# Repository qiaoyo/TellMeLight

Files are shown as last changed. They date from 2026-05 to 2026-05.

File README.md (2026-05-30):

# TellMeLight

TellMeLight is a USB-connected AI hardware design for visualizing local AI sessions as a persistent six-slot light queue.

Current milestone: local software simulation plus a Rev A KiCad hardware baseline. No physical PCB or USB device is required yet.

## Local Commands

Run all tests on Windows:

```powershell
powershell -ExecutionPolicy Bypass -File tools/run-node.ps1 --test host/test/*.test.js
```

Start the local Host Bridge:

```powershell
powershell -ExecutionPolicy Bypass -File tools/run-node.ps1 host/src/server-cli.js
```

Send a repeatable demo event sequence while the Host Bridge is running:

```powershell
powershell -ExecutionPolicy Bypass -File tools/run-node.ps1 host/src/demo-client.js
```

Send individual adapter-style events:

```powershell
powershell -ExecutionPolicy Bypass -File tools/run-node.ps1 host/src/event-cli.js started --id codex-1 --source codex --title "Implement firmware"
powershell -ExecutionPolicy Bypass -File tools/run-node.ps1 host/src/event-cli.js approval --id codex-1 --source codex
powershell -ExecutionPolicy Bypass -File tools/run-node.ps1 host/src/event-cli.js done --id codex-1 --source codex
```

Wrap a local command as a TellMeLight session:

```powershell
$node = powershell -ExecutionPolicy Bypass -File tools/run-node.ps1 -Eval "console.log(process.execPath)"
& $node host/src/process-cli.js --source codex --id codex-1 --title "Codex run" -- codex --help
& $node host/src/process-cli.js --source smoke --id process-smoke -- powershell -NoProfile -Command "exit 0"
```

Run a real Windows Codex request as a TellMeLight session:

```powershell
$env:TELLMELIGHT_CODEX_PROXY = "http://127.0.0.1:7892"
$node = powershell -ExecutionPolicy Bypass -File tools/run-node.ps1 -Eval "console.log(process.execPath)"
& $node host/src/codex-cli.js exec -C . --sandbox read-only "Reply with exactly: TellMeLight codex smoke ok"
& $node host/src/codex-cli.js resume --last "Continue the previous TellMeLight test"
```

The package script for the same adapter is `tml-codex`.

Open the static simulator:

```text
simulator/index.html
```

Generate the Rev A KiCad hardware baseline:

```powershell
node tools/hardware/generate-rev-a-kicad.mjs
```

Generate the Rev A1 JLC-oriented hardware baseline:

```powershell
powershell -ExecutionPolicy Bypass -File tools/run-node.ps1 tools/hardware/generate-rev-a1-kicad.mjs
```

Run KiCad CLI checks with the installed Windows KiCad 10.0 path:

```powershell
& E:\kicad\bin\kicad-cli.exe sch erc --format json -o hardware/outputs/rev_a/erc.json hardware/kicad/tellmelight_rev_a/tellmelight_rev_a.kicad_sch
& E:\kicad\bin\kicad-cli.exe pcb drc --format json -o hardware/outputs/rev_a/drc.json hardware/kicad/tellmelight_rev_a/tellmelight_rev_a.kicad_pcb
& E:\kicad\bin\kicad-cli.exe sch erc --format json -o hardware/outputs/rev_a1/erc.json hardware/kicad/tellmelight_rev_a1/tellmelight_rev_a1.kicad_sch
& E:\kicad\bin\kicad-cli.exe pcb drc --format json -o hardware/outputs/rev_a1/drc.json hardware/kicad/tellmelight_rev_a1/tellmelight_rev_a1.kicad_pcb
```

## Simulator Interaction

- Click any of the six light slots to select it.
- Use `Set Running`, `Set Approval`, `Set Done`, or `Set Error` to update the selected session.
- Use `Clear Selected` to remove the selected visible session and compact later sessions left.
- `Add Running` appends a new running session on the newest/rightmost side.

## Milestone 1 Contents

- FIFO session model.
- Local API event schema.
- HID display frame encoder.
- Browser simulator.
- Hardware architecture notes.
- Generic process wrapper adapter.
- Direct Windows Codex JSON session adapter.
- Rev A KiCad hardware baseline with BOM, PCB floorplan, and power-budget simulation.
- Rev A1 JLC-oriented KiCad baseline with 4-layer PCB, JLC sourcing table, pogo/debug pads, and manufacturing readiness notes.

## Out Of Scope For Milestone 1

- Real USB HID writer.
- Firmware build.
- Fabrication-ready schematic signoff, final routing, enclosure CAD, and optical validation.
- Tool-specific log parsers for Codex, Claude, Cursor, or other AI tools.

## Design Docs

- `docs/superpowers/specs/2026-05-29-tellmelight-design.md`
- `docs/superpowers/specs/2026-05-30-rev-a-kicad-hardware-design.md`
- `docs/superpowers/specs/2026-05-30-rev-a1-jlc-fabrication-candidate-design.md`
- `docs/superpowers/specs/2026-05-29-adapter-foundation-design.md`
- `docs/adapters/contract.md`
- `docs/superpowers/brainstorm/2026-05-29-tellmelight-progress.md`
- `docs/superpowers/plans/2026-05-29-local-simulation-foundation.md`
- `docs/superpowers/plans/2026-05-30-rev-a-kicad-hardware.md`
- `docs/superpowers/plans/2026-05-30-rev-a1-jlc-fabrication-candidate.md`

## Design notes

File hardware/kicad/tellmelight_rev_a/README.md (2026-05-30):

# TellMeLight Rev A KiCad Project

Generated: 2026-05-30

## Contents

- `tellmelight_rev_a.kicad_pro`: KiCad project.
- `tellmelight_rev_a.kicad_sch`: block-level schematic/net plan for Rev A.
- `tellmelight_rev_a.kicad_sym` and `sym-lib-table`: local placeholder symbols so KiCad can export a review BOM.
- `tellmelight_rev_a.kicad_pcb`: PCB placement baseline with real KiCad stock footprints.

## Important Boundary

This is a Rev A CAD baseline for review. It is not a fabrication release until the pin-by-pin schematic, routing, footprint models, and DFM are reviewed.

## Visual Mapping

- D1 and D2: left long bar, oldest side.
- D3: left middle short bar.
- D4: right middle short bar.
- D5 and D6: right long bar, newest side.

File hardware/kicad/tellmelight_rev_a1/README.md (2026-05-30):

# TellMeLight Rev A1 KiCad Project

Generated: 2026-05-30

## Contents

- `tellmelight_rev_a1.kicad_pro`: KiCad project.
- `tellmelight_rev_a1.kicad_sch`: block-level schematic/net plan for Rev A1.
- `tellmelight_rev_a1.kicad_sym` and `sym-lib-table`: local symbols so KiCad can export a review BOM.
- `tellmelight_rev_a1.kicad_pcb`: 4-layer PCB floorplan with stock KiCad footprints.

## Important Boundary

This is a Rev A1 JLC-oriented CAD baseline for review. It is not a fabrication release until the pin-by-pin schematic, routing, footprint models, JLC BOM matching, and DFM are reviewed.

## Manufacturing Direction

- 4-layer PCB.
- Double-sided SMT assembly.
- No assumed user hand-soldering.
- Pogo/test pads replace the visible SWD header direction.
- Front side is kept mostly optical; back side carries logic, USB, power, and service controls.

## Visual Mapping

- D1 and D2: left long bar, oldest side.
- D3: left middle short bar.
- D4: right middle short bar.
- D5 and D6: right long bar, newest side.

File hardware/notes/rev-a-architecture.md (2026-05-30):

# TellMeLight Rev A Hardware Architecture Notes

Rev A is now a KiCad hardware baseline for an integrated USB device. It is meant for design review and iteration, not direct fabrication signoff.

## Selected Direction

- USB-C for power and data.
- RP2040-class USB MCU.
- LP5024-class I2C RGB LED driver.
- six RGB light zones using 18 LED driver channels.
- Four visible diffuser bars:
  - Left long bar has two zones.
  - Left middle bar has one zone.
  - Right middle bar has one zone.
  - Right long bar has two zones.

## KiCad Baseline Boundary

This milestone creates:

- KiCad project files.
- Block-level schematic/net-plan notes.
- PCB floorplan and component placement using real KiCad stock footprints.
- Rev A BOM.
- Power-budget simulation notes.
- KiCad CLI ERC, DRC, and export artifacts when the local KiCad installation supports them.

This milestone does not complete pin-by-pin schematic signoff, final routing, enclosure CAD, diffuser optical validation, or release-to-fabrication DFM.

## Open Hardware Questions

- Whether each light zone can use one RGB LED or needs multiple LEDs for smoother diffusion.
- Exact USB-C protection and ESD component choices.
- Exact LP5024 sourcing option; the baseline uses the 32-pin 4 x 4 mm VQFN/WQFN footprint class.
- Mechanical light-isolation wall thickness between split long-bar zones.

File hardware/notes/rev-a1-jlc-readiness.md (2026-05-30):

# Rev A1 JLC Readiness Notes

Date: 2026-05-30

Rev A1 is a local fabrication-candidate baseline, not an order release.

## Confirmed Direction

- No assumed user hand-soldering.
- JLC DFM review before ordering.
- double-sided SMT assembly pricing and capability check.
- LP5024 VQFN exposed-pad paste and thermal-pad review.
- RGB LED pinout verification against the final JLC selected part.
- USB-C connector footprint and shell grounding review.

## Current JLC Candidate Parts

| Designator | Part | JLC candidate |
| --- | --- | --- |
| U1 | RP2040 | C2040 |
| U2 | LP5024RSMR | C427525 |
| U3 | W25Q32JVSSIQ | C82344 |
| U4 | AP2112K-3.3TRG1 | C51118 |
| U5 | TPD2EUSB30DRTR | C94934 |
| J1 | TYPE-C-31-M-12 | C165948 |
| D1-D6 | S4-3528RGBTA-A | C2827321 |

## Remaining Order Blockers

- Replace block-level schematic review symbols with a pin-by-pin schematic before fabrication.
- Verify the 4-pin RGB LED pad mapping against the final part datasheet.
- Review USB D+/D- routing, ESD placement, and differential pair geometry.
- Review 4-layer stackup, impedance assumptions, and copper pours against the selected JLC service.
- Export JLC BOM and CPL files in the exact order-site format after final component matching.
- Decide whether the first paid order uses black solder mask plus ENIG or a lower-cost engineering finish.

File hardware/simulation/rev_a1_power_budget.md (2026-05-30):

# Rev A1 Power Budget Simulation

Date: 2026-05-30

This is a local engineering current budget for the KiCad Rev A1 JLC-oriented baseline. It is not a SPICE model.

USB current target: keep normal operation comfortably below 500 mA.

| Scenario | 3V3 load | LED channels on | LED current/channel | LED rail current | Approx USB current | LDO dissipation |
| --- | ---: | ---: | ---: | ---: | ---: | ---: |
| Idle off | 38 mA | 0 | 0 mA | 0 mA | 38 mA | 65 mW |
| Typical visible load | 45 mA | 18 | 5 mA | 90 mA | 135 mA | 77 mW |
| Breathing peak | 50 mA | 18 | 10 mA | 180 mA | 230 mA | 85 mW |
| Worst-case all channels | 70 mA | 18 | 20 mA | 360 mA | 430 mA | 119 mW |

## Interpretation

- Typical visible load keeps the device comfortably inside the USB current target.
- Worst-case all channels still fits the target budget on paper, but firmware should cap default brightness well below that state.
- The AP2112K-class LDO only supplies 3V3 logic current; LED current is budgeted on the USB VBUS LED rail.
- The S4-3528RGBTA-A RGB LED candidate remains a sample-and-review item because optical output and diffuser losses will drive the final current limit.

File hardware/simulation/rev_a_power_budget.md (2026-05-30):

# Rev A Power Budget Simulation

Date: 2026-05-30

This is a local engineering current budget for the KiCad Rev A baseline. It is not a SPICE model.

| Scenario | 3V3 load | LED channels on | LED current/channel | LED rail current | Approx USB current | LDO dissipation |
| --- | ---: | ---: | ---: | ---: | ---: | ---: |
| Idle off | 38 mA | 0 | 0 mA | 0 mA | 38 mA | 65 mW |
| Typical visible load | 45 mA | 18 | 5 mA | 90 mA | 135 mA | 77 mW |
| Breathing peak | 50 mA | 18 | 10 mA | 180 mA | 230 mA | 85 mW |
| Worst-case all channels | 70 mA | 18 | 20 mA | 360 mA | 430 mA | 119 mW |

## Interpretation

- Typical visible load keeps the device comfortably inside a 500 mA USB current budget.
- Worst-case all channels still fits the target budget on paper, but firmware should cap default brightness well below that state.
- The AP2112K-class LDO only supplies 3V3 logic current; LED current is budgeted on the USB VBUS LED rail.
- The RGB LED part remains a sample-and-review item because optical output and diffuser losses will drive the final current limit.

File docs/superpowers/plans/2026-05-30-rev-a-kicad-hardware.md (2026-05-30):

# Rev A KiCad Hardware Implementation Plan

> **For agentic workers:** REQUIRED SUB-SKILL: Use superpowers:subagent-driven-development (recommended) or superpowers:executing-plans to implement this plan task-by-task. Steps use checkbox (`- [ ]`) syntax for tracking.

**Goal:** Add a verified Rev A KiCad hardware baseline for the integrated TellMeLight USB light device.

**Architecture:** A small Node generator writes deterministic hardware documentation, BOM tables, and KiCad project scaffolding. A KiCad Python generator uses the installed KiCad 10.0 `pcbnew` API to create the PCB with real library footprints and the approved six-zone/four-bar placement. KiCad CLI then runs ERC/DRC and exports review/manufacturing artifacts.

**Tech Stack:** KiCad 10.0.3 CLI, KiCad `pcbnew` Python API, JavaScript ES modules, Node `node:test`, PowerShell runner.

---

## File Structure

- Create `hardware/kicad/tellmelight_rev_a/`: KiCad project, schematic, board, local symbol metadata, and generated design README.
- Create `hardware/bom/rev_a_bom.csv`: human-readable baseline BOM.
- Create `hardware/simulation/rev_a_power_budget.csv`: machine-readable current budget.
- Create `hardware/simulation/rev_a_power_budget.md`: readable power simulation notes.
- Create `hardware/outputs/rev_a/`: ERC, DRC, and exported KiCad output files.
- Create `tools/hardware/generate-rev-a-kicad.mjs`: deterministic project/document generator.
- Create `tools/hardware/generate_rev_a_board.py`: KiCad `pcbnew` board generator.
- Create `host/test/hardware-assets.test.js`: repository tests for hardware outputs and decisions.
- Modify `hardware/notes/rev-a-architecture.md`: move from "no PCB" note to Rev A baseline note.
- Modify `docs/superpowers/brainstorm/2026-05-29-tellmelight-progress.md`: record this checkpoint.
- Modify `README.md`: add the hardware workspace and KiCad commands.

## Task 1: Spec And Plan

- [ ] Save the approved Rev A design spec at `docs/superpowers/specs/2026-05-30-rev-a-kicad-hardware-design.md`.
- [ ] Save this implementation plan at `docs/superpowers/plans/2026-05-30-rev-a-kicad-hardware.md`.
- [ ] Run `git diff --check`.
- [ ] Commit as `docs: plan rev a kicad hardware`.

## Task 2: Hardware Artifact Tests

- [ ] Add `host/test/hardware-assets.test.js`.
- [ ] Tests must assert the Rev A spec mentions `RP2040`, `LP5024`, `USB-C`, `six logical session slots`, and `VQFN-32`.
- [ ] Tests must assert the generated BOM contains `RP2040`, `LP5024`, `W25Q32`, `AP2112K`, `TPD2EUSB30`, `USB_C`, and `RGB_LED`.
- [ ] Tests must assert the generated PCB contains the required references `U1`, `U2`, `J1`, `D1` through `D6`, `SWD1`, `SW1`, and `SW2`.
- [ ] Run `powershell -ExecutionPolicy Bypass -File tools/run-node.ps1 --test host/test/hardware-assets.test.js` and confirm the new tests fail before generation.

## Task 3: Generators And Documentation

- [ ] Add `tools/hardware/generate-rev-a-kicad.mjs` with deterministic output paths.
- [ ] Add `tools/hardware/generate_rev_a_board.py` that loads KiCad stock footprints and places the core Rev A components.
- [ ] Update `hardware/notes/rev-a-architecture.md` with the actual KiCad baseline scope.
- [ ] Update `README.md` with hardware commands and artifact paths.
- [ ] Update the Superpowers progress log with the Rev A hardware checkpoint.

## Task 4: Generate Rev A Assets

- [ ] Run `node tools/hardware/generate-rev-a-kicad.mjs`.
- [ ] Confirm these files are created:
  - `hardware/kicad/tellmelight_rev_a/tellmelight_rev_a.kicad_pro`
  - `hardware/kicad/tellmelight_rev_a/tellmelight_rev_a.kicad_sch`
  - `hardware/kicad/tellmelight_rev_a/tellmelight_rev_a.kicad_pcb`
  - `hardware/bom/rev_a_bom.csv`
  - `hardware/simulation/rev_a_power_budget.csv`
  - `hardware/simulation/rev_a_power_budget.md`
- [ ] Run `powershell -ExecutionPolicy Bypass -File tools/run-node.ps1 --test host/test/hardware-assets.test.js` and confirm the hardware tests pass.

## Task 5: KiCad CLI Verification And Exports

- [ ] Run `E:\kicad\bin\kicad-cli.exe sch erc --format json -o hardware/outputs/rev_a/erc.json hardware/kicad/tellmelight_rev_a/tellmelight_rev_a.kicad_sch`.
- [ ] Run `E:\kicad\bin\kicad-cli.exe sch export bom -o hardware/outputs/rev_a/bom_from_kicad.csv hardware/kicad/tellmelight_rev_a/tellmelight_rev_a.kicad_sch`.
- [ ] Run `E:\kicad\bin\kicad-cli.exe sch export netlist -o hardware/outputs/rev_a/netlist.xml hardware/kicad/tellmelight_rev_a/tellmelight_rev_a.kicad_sch`.
- [ ] Run `E:\kicad\bin\kicad-cli.exe pcb drc --format json -o hardware/outputs/rev_a/drc.json hardware/kicad/tellmelight_rev_a/tellmelight_rev_a.kicad_pcb`.
- [ ] Run `E:\kicad\bin\kicad-cli.exe pcb export gerbers -o hardware/outputs/rev_a/gerbers hardware/kicad/tellmelight_rev_a/tellmelight_rev_a.kicad_pcb`.
- [ ] Run `E:\kicad\bin\kicad-cli.exe pcb export drill -o hardware/outputs/rev_a/drill hardware/kicad/tellmelight_rev_a/tellmelight_rev_a.kicad_pcb`.
- [ ] Run `E:\kicad\bin\kicad-cli.exe pcb export pos -o hardware/outputs/rev_a/pos hardware/kicad/tellmelight_rev_a/tellmelight_rev_a.kicad_pcb`.
- [ ] Run `E:\kicad\bin\kicad-cli.exe pcb export step -o hardware/outputs/rev_a/tellmelight_rev_a.step hardware/kicad/tellmelight_rev_a/tellmelight_rev_a.kicad_pcb`.
- [ ] Run `E:\kicad\bin\kicad-cli.exe pcb render -o hardware/outputs/rev_a/tellmelight_rev_a_top.png --side top --width 1600 --height 1200 hardware/kicad/tellmelight_rev_a/tellmelight_rev_a.kicad_pcb`.
- [ ] Record any warnings in `hardware/outputs/rev_a/verification-summary.md`.

## Task 6: Final Repository Verification

- [ ] Run `powershell -ExecutionPolicy Bypass -File tools/run-node.ps1 --test host/test/*.test.js`.
- [ ] Run `git diff --check`.
- [ ] Review `git status --short`.
- [ ] Commit as `feat: add rev a kicad hardware baseline`.
- [ ] Push `feature/local-simulation-foundation`.

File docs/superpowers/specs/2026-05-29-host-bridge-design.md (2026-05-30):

# TellMeLight Host Bridge Design

Date: 2026-05-29

## Goal

Build a local-only Host Bridge service that turns normalized AI session events into the six-slot TellMeLight model and streams the current slots to the browser simulator.

This milestone still does not touch real PCB, firmware, or USB hardware.

## Scope

Included:

- Local HTTP service using Node built-in modules.
- `POST /v1/events` for normalized session events.
- `GET /v1/slots` for the current six-slot state.
- `GET /v1/stream` using Server-Sent Events for live simulator updates.
- A small manual event client for local demos.
- Simulator support for connecting to the Host Bridge, while keeping manual buttons as a fallback.

Excluded:

- Real USB HID device writing.
- WebSocket support.
- Real Codex, Claude, Cursor, or local-agent adapters.
- Persistence across process restarts.

## Architecture

The Host Bridge is a thin service layer around the existing tested core:

- `host/src/schema.js` validates and normalizes external event payloads.
- `host/src/fifo.js` owns session ordering and state transitions.
- A new bridge state module owns the mutable in-memory model and subscriber notification.
- A new HTTP server module maps routes to bridge operations.
- A demo client sends example events to the service.
- The simulator first tries the service stream. If unavailable, it stays usable in manual mode.

This keeps adapter work separate from the core display model. Future tool adapters can send the same event payloads to `POST /v1/events`.

## API

`GET /v1/slots`

- Returns HTTP 200 JSON.
- Body contains `revision` and `slots`.
- Each slot includes `slot`, `id`, `source`, `title`, `state`, and `updatedAt`.
- Empty slots are represented as `id: null`, `state: "idle"`.

`POST /v1/events`

- Accepts JSON with `source`, `session_id`, `event`, optional `state`, optional `title`, optional `time`, and optional `outcome`.
- Uses the existing normalizer and FIFO core.
- Returns HTTP 202 JSON containing the updated slot snapshot.
- Invalid JSON or invalid event payloads return HTTP 400 JSON with an `error` field.

`GET /v1/stream`

- Returns `text/event-stream`.
- Sends the current snapshot immediately.
- Sends another snapshot whenever `POST /v1/events` changes the model.
- Uses event name `slots`.

## Simulator Behavior

On load, the simulator opens `/v1/stream` against `http://localhost:8787`.

- If the stream connects, incoming slot snapshots drive the light display and JSON panel.
- Manual controls remain available and send events to `POST /v1/events`.
- If the service is unavailable or a POST fails, the simulator falls back to the existing in-browser manual state.
- Selected-slot UI remains local to the simulator; the Host Bridge only owns session state.

## Manual Demo

A new demo script sends a repeatable sequence:

1. Start session A.
2. Start session B.
3. Change A to approval.
4. End B as done.
5. Start enough extra sessions to demonstrate FIFO movement.

The script targets `http://localhost:8787` by default.

## Testing

Tests cover:

- Slot snapshot shape from the bridge state module.
- Event application and subscriber notification.
- HTTP `GET /v1/slots`.
- HTTP `POST /v1/events` success and invalid-payload failure.
- SSE stream sends the current snapshot and updates.
- Simulator assets contain the Host Bridge connection and fallback hooks.

Full verification remains:

```powershell
powershell -ExecutionPolicy Bypass -File tools/run-node.ps1 --test host/test/*.test.js
```

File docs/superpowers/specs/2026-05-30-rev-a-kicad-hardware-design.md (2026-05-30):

# Rev A KiCad Hardware Design

Date: 2026-05-30

## Goal

Create the first local KiCad hardware baseline for TellMeLight: a USB-C connected, integrated PCB that drives six persistent AI-session light zones through a four-bar diffuser layout.

This baseline is intended for design review, firmware bring-up planning, and PCB iteration. It is not a release-to-fabrication signoff without a human schematic, footprint, and DFM review.

## Approved Product Direction

- Wired USB-C for power and data.
- No development board in the product; the PCB is integrated.
- Six logical session slots are kept as a FIFO queue.
- Idle slots are off.
- Running and approval states can breathe in firmware.
- Done and error states remain visible until the user or host clears them.
- Visual core uses four ByteDance-style vertical diffuser bars:
  - Left long bar contains two light zones.
  - Left middle short bar contains one light zone.
  - Right middle short bar contains one light zone.
  - Right long bar contains two light zones.
- The left long bar is slightly shorter than the right long bar.
- The two middle bars are equal size; the left short bar sits lower and the right short bar sits only slightly higher.
- Bar shapes are soft, rounded, irregular trapezoids:
  - Left long, right long, and left middle bars have their shorter side facing right.
  - Right middle bar has its shorter side facing left.

## Electrical Architecture

### USB And MCU

- Use an RP2040-class USB microcontroller as the main controller.
- Use USB full-speed data on the USB-C receptacle.
- Add 27 ohm series resistors on USB D+ and D- near the MCU.
- Add USB ESD protection close to the USB-C connector.
- Add CC pull-down resistors so the board enumerates as a USB-C device.
- Use an external QSPI flash for RP2040 firmware storage.
- Add 12 MHz crystal support for the RP2040 clock.
- Expose SWD, reset, boot select, 3V3, and GND pads for bring-up.

### LED Driver

- Use an LP5024-class 24-channel I2C constant-current RGB LED driver.
- Use 18 channels for six RGB zones; leave six channels reserved.
- Power logic from 3V3 and LED anodes from the USB 5V LED rail unless review later moves LED power to 3V3.
- Use one common-anode RGB LED per zone for Rev A. The mechanical diffuser may later require multiple emitters per zone, but that belongs to Rev B after optical tests.
- I2C pull-ups live on the 3V3 rail.
- Address pins are strapped for a single driver at the base address.

### Power

- USB VBUS enters through input protection and feeds:
  - 5V LED rail.
  - 3V3 regulator for MCU, flash, and LED driver logic.
- Use an AP2112K-3.3-class LDO in SOT-23-5 for the first baseline.
- Size decoupling locally:
  - USB input bulk capacitance near the connector/regulator.
  - 3V3 regulator input/output capacitors near the LDO.
  - One local 100 nF decoupler per IC supply cluster.
  - LED rail bulk capacitance near the LED driver/LED zones.

## Mechanical And PCB Intent

- PCB outline is a compact near-square core display module with enough room for USB-C, programming pads, and diffuser alignment.
- Front-side LED placement follows the four-bar visual layout.
- Silkscreen and drawing layers mark diffuser bar boundaries, split points in long bars, and session indices.
- Rev A PCB is a placement and routing baseline:
  - The KiCad board must contain real footprints for the main components.
  - The LED geometry must match the approved visual direction.
  - The first generated PCB may use simple routing scaffolds and explicit review notes rather than final hand-tuned high-density routing.

## BOM Intent

The baseline BOM must include:

- RP2040 MCU, QFN-56 7 x 7 mm.
- LP5024 LED driver, VQFN-32 RSM 4 x 4 mm.
- USB-C USB2 receptacle.
- AP2112K-3.3-class LDO.
- TPD2EUSB30-class USB ESD protection.
- W25Q32JVSS-class QSPI flash.
- 12 MHz crystal and load capacitors.
- Six common-anode PLCC-6 RGB LEDs.
- USB resistors, CC resistors, I2C pull-ups, boot/reset passives, decoupling capacitors, and test pads.

## Simulation And Checks

Rev A local simulation means engineering calculation and CAD checks, not SPICE signoff:

- Power budget table for idle, typical, and worst-case LED current.
- KiCad schematic ERC report.
- KiCad PCB DRC report.
- KiCad exports for Gerber, drill, position, STEP, PDF/SVG or rendered preview when supported by the installed KiCad CLI.
- Repository tests that confirm required hardware artifacts and component decisions exist.

## Open Review Items

- Confirm exact RGB LED optical output, viewing angle, color balance, and availability.
- Confirm whether LED anodes stay on USB 5V or move to 3V3 after brightness tests.
- Confirm USB-C receptacle mechanical model and shell grounding strategy.
- Confirm final enclosure, diffuser material, wall thickness, and light isolation.
- Confirm manufacturability of QFN/VQFN assembly for the intended PCB vendor.

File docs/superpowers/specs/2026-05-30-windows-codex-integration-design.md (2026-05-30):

# Windows Codex Integration Design

Date: 2026-05-30

## Goal

Connect TellMeLight directly to the local Windows Codex CLI conversation/session flow.

This is not a generic process wrapper. It uses real `codex exec --json` and `codex exec resume --json` output so TellMeLight can key sessions by Codex `thread_id`.

## Verified Local Codex

- Executable: `codex.exe`
- Version: `codex-cli 0.133.0-alpha.1`
- Install path: VS Code ChatGPT extension Windows binary.
- Working network path: proxy `http://127.0.0.1:7892`.
- Verified request:
  - Command: `codex exec --json -C . --sandbox read-only "Reply with exactly: TellMeLight codex smoke ok"`
  - Observed `thread.started` with a real `thread_id`.
  - Observed final agent message `TellMeLight codex smoke ok`.

## Scope

Included:

- `tml-codex` command for new Codex turns.
- `tml-codex resume` command for continuing a recorded Codex session.
- Real Codex JSONL parsing.
- TellMeLight session ID from Codex `thread_id`.
- Running/done/error mapping from Codex turn and process lifecycle.
- Approval mapping when Codex JSONL contains approval-oriented event or item status fields.
- Proxy override through `--tml-proxy` or `TELLMELIGHT_CODEX_PROXY`.

Excluded:

- Interactive TUI scraping.
- Private Codex database parsing.
- Mutating Codex config files.
- Firmware, HID output, PCB, and schematic work.

## Command Shape

New request:

```powershell
$env:TELLMELIGHT_CODEX_PROXY = "http://127.0.0.1:7892"
$node = powershell -ExecutionPolicy Bypass -File tools/run-node.ps1 -Eval "console.log(process.execPath)"
& $node host/src/codex-cli.js exec -C . --sandbox read-only "Reply with exactly: TellMeLight codex smoke ok"
```

Resume most recent non-interactive Codex session:

```powershell
& $node host/src/codex-cli.js resume --last "Continue the previous TellMeLight test"
```

TellMeLight-only flags:

- `--tml-url`: Host Bridge base URL.
- `--tml-title`: visible title before Codex emits details.
- `--tml-proxy`: proxy URL assigned to `HTTP_PROXY`, `HTTPS_PROXY`, `http_proxy`, and `https_proxy` for the Codex child process.

## Event Mapping

- `thread.started`: send TellMeLight `started` with `state: running` and `session_id` equal to the Codex thread ID.
- `turn.started`: send `state_changed` to `running` if the thread is known.
- JSONL event or item fields containing approval/waiting-for-approval semantics: send `state_changed` to `approval`.
- `turn.completed`: send `ended` with `outcome: success`.
- Codex JSONL error events or non-zero process exit: send `ended` with `outcome: error`.

The CLI passes Codex stdout/stderr through so it remains usable as a Codex command.

## Testing

Unit tests cover command parsing, proxy environment application, JSONL event mapping, and process lifecycle behavior with fake spawn/send functions.

Real smoke test uses the local Windows Codex CLI with proxy `http://127.0.0.1:7892` and a temporary Host Bridge.

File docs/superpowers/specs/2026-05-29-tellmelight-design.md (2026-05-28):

# TellMeLight Design

Date: 2026-05-29

## Summary

TellMeLight is a USB-connected AI hardware device that visualizes local AI sessions through a persistent six-slot light queue. The physical design uses a four-bar, ByteDance-style top-face rhythm while preserving six independent RGB light zones by splitting both long bars into two zones.

The first product direction is an integrated PCB with a USB-C interface, RP2040-class MCU, LP5024-class I2C RGB LED driver, six RGB light zones, a local Host Bridge service, firmware-side light rendering, and a browser simulator for pre-hardware validation.

## Goals

- Design an integrated PCB hardware product, not a breadboard or development-board MVP.
- Connect local AI tools to a small desk light display over USB.
- Show up to six AI sessions as a FIFO queue.
- Keep completed and errored sessions visible until cleared or evicted.
- Build an automation-friendly repo structure where specs, host software, firmware, hardware, and verification can evolve together.
- Use AI-assisted design with explicit verification gates rather than blind one-click hardware generation.

## Non-Goals

- No Wi-Fi or wireless mode in the first hardware target.
- No FPGA or HDL-based implementation unless the architecture changes later.
- No PCB layout before the six-slot logic and simulator are executable and testable.
- No direct dependency on a single AI tool's log format in the core state machine.

## Visual Design

The device is a compact desk puck with a rounded rectangular body and four vertical diffuser bars on the top face.

The final silhouette:

- Left long bar is slightly shorter than the right long bar.
- The two middle bars are the same size.
- Left middle bar sits lower.
- Right middle bar sits only slightly higher than the left middle bar.
- The visual style intentionally follows a ByteDance-style four-bar rhythm.

The four visible bars represent six internal light zones:

- Left long bar: two internal zones.
- Left middle short bar: one zone.
- Right middle short bar: one zone.
- Right long bar: two internal zones.

## Session Queue

The six light zones form a FIFO queue.

- New sessions enter the rightmost slot.
- Existing sessions shift left by one slot when a new session starts.
- If a seventh new session arrives, slot 1, the top of the left long bar, is evicted.
- Evicted sessions can remain in host-side history but are no longer displayed.
- Completed and errored sessions remain visible until evicted or explicitly cleared.
- `cleared` removes a target session, compacts remaining visible sessions left, and leaves the newest-side empty slot idle.

## State Language

Each visible slot has one state:

- `running`: cyan/blue, continuous slow breathing.
- `approval`: amber, continuous attention pulse.
- `done`: green, persistent steady light.
- `error`: red, persistent steady light or slow warning pulse.
- `idle`: off.

Animation is persistent for active states; it is not a one-time notification. Done and error states must remain visible so the user can notice them later.

## Hardware Architecture

The confirmed first hardware target:

- USB-C for power and data.
- RP2040-class USB MCU.
- LP5024-class I2C RGB LED driver.
- Six RGB light zones using 18 LED driver channels.
- Integrated PCB.

The LED driver route is preferred over addressable RGB LEDs because it is more maintainable and product-like:

- MCU writes stable I2C commands instead of timing-sensitive one-wire LED data.
- LED current and color behavior are controlled by a dedicated driver.
- Firmware and hardware tests can isolate the driver, channels, and zones.
- The architecture leaves channel headroom with a 24-channel driver.

Open hardware decision:

- Decide whether each light zone uses one RGB LED or multiple LEDs under the same diffuser zone. If each zone needs multiple LEDs for smoother diffusion, the design may use more driver channels or parallel same-color LEDs with careful current design.

## Software Boundary

TellMeLight is split into host software, device firmware, and hardware output.

Host Bridge owns:

- Local AI tool integration.
- Session discovery.
- Normalized event ingestion.
- Session registry.
- FIFO queue state machine.
- Persistence and history.
- Slot output to simulator and USB device.

Device firmware owns:

- USB HID frame receive.
- Frame validation.
- State-to-light rendering.
- Breathing and pulse curves.
- Global brightness limits.
- I2C updates to the LP5024-class LED driver.

The LED driver owns:

- PWM/current output for the RGB channels.

## Local API

The Host Bridge exposes a local API for adapters and debugging:

- `POST /v1/events`: receive normalized session events.
- `GET /v1/slots`: return the current six-slot state.
- `WS /v1/stream`: stream slot updates to simulator or dashboard clients.

Minimal event payload:

```json
{
  "source": "codex",
  "session_id": "abc123",
  "event": "started",
  "state": "running",
  "title": "optional short label",
  "time": "2026-05-29T00:00:00+08:00"
}
```

Event semantics:

- `started`: if `session_id` is new, shift FIFO left and insert into slot 6 as `running`; if known, update in place.
- `state_changed`: update known sessions in place; create unknown sessions to keep adapters forgiving.
- `ended`: does not remove the session; sets state to `done` unless outcome is `error`.
- `cleared`: removes a visible session, compacts remaining sessions left, and sets the empty newest-side slot to idle.
- `evicted`: internal Host Bridge log/UI event when a seventh new session pushes slot 1 out.

## USB Device Protocol

Host-side APIs remain JSON-based. The product device protocol is USB HID.

Product path:

- USB HID output report.
- Fixed-size binary frame, initially 64 bytes.
- No user-facing serial port required.

Development path:

- Optional USB CDC serial debug console in development firmware.
- CDC is for logs and manual testing, not the primary product protocol.

Proposed 64-byte display frame:

- `magic[2]`: `TL`.
- `version`: protocol version.
- `seq`: incrementing frame number.
- `brightness`: global brightness, `0..255`.
- `flags`: global display options.
- `slots[6]`: each slot carries `state`, `anim`, `intensity`, `age`, `label_hash`, and reserved bytes.
- `crc8`: lightweight frame check.

The firmware owns the default state palette. Host-side RGB overrides can be added later as an extension, but the first protocol should send display intent rather than raw colors.

## Firmware Rendering

Host Bridge sends slot states only when FIFO or session status changes. It does not stream every animation frame.

Firmware computes animations locally:

- Keeps the last valid frame.
- Renders breathing and pulse curves on the device.
- Updates the LED driver at a steady frame rate.
- Ignores invalid frames.

Failsafe behavior:

- USB connected but no recent update: keep the last valid frame.
- Host heartbeat lost for a longer timeout: optionally dim all active slots to show stale data.
- Invalid frame: ignore it and keep the previous valid frame.

## Host Bridge Modules

Recommended internal structure:

- Inputs:
  - HTTP event API.
  - Manual test client.
  - Tool-specific adapters for Codex, Claude, Cursor, and future local agents.
- Core:
  - Event validation.
  - Session registry.
  - FIFO queue state machine.
  - Persistence and history.
- Outputs:
  - USB HID device writer.
  - Web simulator stream.
  - Debug REST API.
  - Logs.

Design rules:

- Adapters are disposable and translate tool-specific signals into normalized events.
- FIFO core is durable and tested independently.
- Outputs are replaceable, so the same six-slot model can drive a simulator before hardware exists.

## Repository Structure

Initial repo areas:

- `docs/`: design specs, progress logs, decisions, checklists.
- `host/`: Bridge service, API, FIFO core, adapters, simulator connection.
- `firmware/`: RP2040 firmware, HID receive, animation renderer, LP5024-class driver.
- `hardware/`: PCB, symbols/footprints, enclosure notes, manufacturing outputs.
- `simulator/`: browser-visible light simulator and visual validation tools.
- `tools/`: automation scripts for checks, generated outputs, and design support.

## Automation Pipeline

The automation goal is AI-assisted design with repeatable checks.

Pipeline stages:

- Spec: requirements, state semantics, six-slot mapping, selected components.
- Schematic: USB-C input, RP2040-class MCU, LP5024-class RGB LED driver, power, ESD/protection, debug/programming pads.
- PCB: board outline, LED placement, diffuser and light-isolation assumptions, routing, DRC.
- Firmware: HID receive, renderer, LP5024-class driver.
- Host: local API, FIFO model, simulator, USB HID writer.

Verification gates:

- Hardware:
  - Electrical rule check.
  - PCB design rule check.
  - BOM completeness.
  - Footprint presence.
  - USB/power review checklist.
- Software:
  - FIFO state-machine tests.
  - API schema tests.
  - HID frame encoder tests.
  - Firmware renderer tests.
  - Simulator screenshot checks.

## First Implementation Milestone

Create a repo skeleton and executable software simulation before starting PCB layout.

Milestone scope:

- Host FIFO core with tests.
- Local event API schema.
- Browser simulator showing the refined four-bar, six-zone layout.
- HID frame encoder tests.
- Hardware component decision record.
- Initial hardware notes for USB-C, RP2040-class MCU, LP5024-class LED driver, diffuser zones, and PCB constraints.

PCB layout is intentionally deferred until the six-slot logic and simulator are testable.

## Risks And Open Questions

- Legal/brand risk: the visual language intentionally follows a ByteDance-style four-bar rhythm because the user is a ByteDance designer. The design should still be handled carefully if the project becomes public or commercial.
- Diffuser risk: long bars with two internal zones require good light isolation to avoid confusing session boundaries.
- LED count risk: one RGB LED per zone may not diffuse evenly enough; multiple LEDs per zone may change driver/channel planning.
- USB HID details need exact report descriptor and host library choice.
- The first real adapter target is not yet selected.

## Acceptance Criteria

The design is ready for implementation planning when:

- The user approves this spec.
- The first milestone is limited to repo skeleton, host FIFO logic, simulator, protocol encoder tests, and hardware notes.
- No PCB layout work starts before software simulation and design checks exist.

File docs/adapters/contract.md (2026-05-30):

# TellMeLight Adapter Contract

TellMeLight adapters translate tool-specific activity into normalized local events for the Host Bridge.

Adapters do not own FIFO ordering, LED state rendering, USB output, or simulator behavior. They only send events to:

```text
POST http://127.0.0.1:8787/v1/events
```

## Required Fields

Every event payload must include:

- `source`: the adapter or tool name, such as `codex`, `claude`, `cursor`, or `manual`.
- `session_id`: a stable ID for one AI session.
- `event`: one of `started`, `state_changed`, `ended`, or `cleared`.

Optional fields:

- `state`: one of `running`, `approval`, `done`, or `error`.
- `title`: a human-readable label for the session.
- `time`: adapter-supplied timestamp string.
- `outcome`: for `ended`, one of `success`, `done`, or `error`.

## Event Semantics

- `started`
  - Creates or updates a visible session.
  - Defaults to `running`.
- `state_changed`
  - Updates an existing session in place.
  - Unknown sessions are inserted as new visible sessions.
- `ended`
  - Keeps the session visible.
  - `outcome: "success"` or `outcome: "done"` maps to `done`.
  - `outcome: "error"` maps to `error`.
- `cleared`
  - Removes the visible session and compacts later sessions left.

## Payload Example

```json
{
  "source": "codex",
  "session_id": "codex-1",
  "event": "started",
  "state": "running",
  "title": "Implement firmware"
}
```

## CLI Examples

Start a session:

```powershell
powershell -ExecutionPolicy Bypass -File tools/run-node.ps1 host/src/event-cli.js started --id codex-1 --source codex --title "Implement firmware"
```

Mark it as waiting for approval:

```powershell
powershell -ExecutionPolicy Bypass -File tools/run-node.ps1 host/src/event-cli.js approval --id codex-1 --source codex
```

Mark it done:

```powershell
powershell -ExecutionPolicy Bypass -File tools/run-node.ps1 host/src/event-cli.js done --id codex-1 --source codex
```

Mark it errored:

```powershell
powershell -ExecutionPolicy Bypass -File tools/run-node.ps1 host/src/event-cli.js error --id codex-1 --source codex
```

Clear it:

```powershell
powershell -ExecutionPolicy Bypass -File tools/run-node.ps1 host/src/event-cli.js cleared --id codex-1 --source codex
```

Use a non-default Host Bridge URL:

```powershell
powershell -ExecutionPolicy Bypass -File tools/run-node.ps1 host/src/event-cli.js started --id local-1 --url http://127.0.0.1:9000
```

## Process Wrapper

`host/src/process-cli.js` is the generic local process adapter. Use it when a tool can be represented as a command that starts, runs, and exits. The wrapper emits:

- `started` before launching the child process.
- `ended` with `outcome: "success"` when the child exits with code `0`.
- `ended` with `outcome: "error"` when the child exits non-zero or cannot be spawned.

The wrapper preserves the child process exit code. TellMeLight event delivery failures are printed as warnings and do not block the wrapped command.

Wrapper flags must come before `--`. Everything after `--` is treated as the child command and its arguments:

```powershell
$node = powershell -ExecutionPolicy Bypass -File tools/run-node.ps1 -Eval "console.log(process.execPath)"
& $node host/src/process-cli.js --source codex --id codex-1 --title "Codex run" -- codex --help
```

The package script name is `tml-run` for environments with `npm` available:

```powershell
npm run tml-run -- --source smoke --id process-smoke -- powershell -NoProfile -Command "exit 0"
```

Useful flags:

- `--source`: adapter or tool name; defaults to `process`.
- `--id`: stable session ID; generated when omitted.
- `--title`: visible session label; defaults to the child command line.
- `--url`: non-default Host Bridge URL.
- `--cwd`: child process working directory.

## Windows Codex Adapter

`host/src/codex-cli.js` is the direct Windows Codex adapter. It runs the local `codex` executable in JSONL mode and uses Codex's real `thread_id` as the TellMeLight `session_id`.

New Codex request:

```powershell
$env:TELLMELIGHT_CODEX_PROXY = "http://127.0.0.1:7892"
$node = powershell -ExecutionPolicy Bypass -File tools/run-node.ps1 -Eval "console.log(process.execPath)"
& $node host/src/codex-cli.js exec -C . --sandbox read-only "Reply with exactly: TellMeLight codex smoke ok"
```

Resume the latest recorded Codex session:

```powershell
& $node host/src/codex-cli.js resume --last "Continue the previous TellMeLight test"
```

The package script name is `tml-codex` for environments with `npm` available:

```powershell
npm run tml-codex -- exec -C . --sandbox read-only "Reply with exactly: TellMeLight codex smoke ok"
```

TellMeLight-only flags:

- `--tml-url`: non-default Host Bridge URL.
- `--tml-title`: visible session label.
- `--tml-proxy`: proxy URL for the Codex child process.

Event mapping:

- Codex `thread.started` sends `started` with `state: running`.
- Codex `turn.started` sends `state_changed` to `running`.
- Approval-like Codex event or item statuses send `state_changed` to `approval`.
- Codex `turn.completed` sends `ended` with `outcome: success`.
- Codex error events or non-zero process exit send `ended` with `outcome: error`.

## Session ID Guidance

Use stable session IDs. If a tool does not provide one, derive an ID from:

- workspace path,
- adapter name,
- process ID,
- or a local session counter.

Avoid using only a timestamp when the same session will emit multiple events.

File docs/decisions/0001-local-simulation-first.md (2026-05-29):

# 0001: Build Local Simulation Before PCB Layout

## Status

Accepted

## Context

TellMeLight is intended to become integrated PCB hardware, but no physical prototype exists yet. The six-session FIFO behavior, state language, and USB display protocol can be verified locally before schematic or PCB layout begins.

## Decision

Build the local software foundation first:

- FIFO state-machine tests.
- Local API event schema tests.
- HID frame encoder tests.
- Browser simulator for the refined four-bar, six-zone layout.
- Hardware architecture notes.

No PCB layout starts until these local pieces are executable and testable.

## Consequences

- We reduce the chance of changing PCB assumptions because of late software model changes.
- The simulator gives immediate visual feedback without waiting for hardware.
- Hardware automation can later use a more stable spec and test suite.

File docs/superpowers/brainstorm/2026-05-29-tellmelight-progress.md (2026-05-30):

# TellMeLight Brainstorm Progress

Date: 2026-05-29

This is a running brainstorm log. It records intermediate decisions before the final Superpowers design spec is written.

## Confirmed Direction

- TellMeLight is an AI hardware device that visualizes local AI sessions through light.
- The first physical target is an integrated PCB, not a breadboard or development-board MVP.
- USB wired connection is the first connectivity mode.
- Hardware simulation and software simulation are acceptable before physical boards exist.
- HDL is not the default simulation route because the product is MCU-based, not FPGA-based.

## Visual Design

- Form factor: desk puck.
- Top-face language: four vertical bars inspired by a ByteDance-style rhythm.
- Final silhouette:
  - Left long bar is slightly shorter than the right long bar.
  - Two middle bars have the same size.
  - Left middle bar sits lower.
  - Right middle bar sits only slightly higher than the left middle bar.
- The device still represents six sessions:
  - Left long bar has two internal zones.
  - Left middle short bar has one zone.
  - Right middle short bar has one zone.
  - Right long bar has two internal zones.

## Session Display Logic

- The six light zones form a FIFO queue.
- New sessions enter the rightmost slot.
- Existing sessions shift left by one slot when a new session starts.
- If more than six sessions exist, the leftmost top slot is evicted.
- Completed and errored sessions remain visible until evicted or explicitly cleared.
- Idle means the zone is off.

## State Language

- Running: cyan/blue, optionally slow breathing.
- Approval: amber, optionally continuous attention pulse.
- Done: green, persistent.
- Error: red, persistent.
- Idle: off.

Resolved:
- Breathing and pulse behavior should be firmware-controlled.

## Hardware Architecture

Confirmed recommendation:
- USB-C.
- RP2040-class USB MCU.
- LP5024-class I2C RGB LED driver.
- Six RGB light zones, requiring 18 LED driver channels.
- LED driver route is preferred over addressable RGB LEDs because it is more maintainable and product-like.

Open point:
- Decide whether each light zone uses one RGB LED or multiple LEDs under the same diffuser zone.

## Software Boundary

Recommended split:
- Host Bridge owns local AI integration, session discovery, FIFO ordering, and persistence.
- Device firmware owns USB receive, state rendering, breathing curves, brightness limits, and LED driver updates.
- LED driver owns PWM/current output.

Recommended local API:
- `POST /v1/events`: receive normalized session events.
- `GET /v1/slots`: return current six-slot state.
- `WS /v1/stream`: stream slot updates to simulator or dashboard.

Next design topic:
- Define event semantics for `started`, `state_changed`, `ended`, `cleared`, and eviction.

## Proposed Event Semantics

Proposed on 2026-05-29 for review:

- `started`
  - If `session_id` is new, shift the FIFO left and insert the session into slot 6 as `running`.
  - If `session_id` already exists, update the existing slot instead of duplicating it.
- `state_changed`
  - If `session_id` exists, update that slot in place.
  - If `session_id` is unknown, create it as a new session so adapters can be forgiving.
- `ended`
  - Does not remove the session from the queue.
  - Sets state to `done` unless the payload says the outcome is `error`.
- `cleared`
  - Explicitly removes a session from the visible queue.
  - Remaining sessions compact left and the newest-side empty slot becomes idle.
  - Confirmed by user.
- Eviction
  - When a seventh new session arrives, slot 1 is evicted from the visible queue.
  - Evicted sessions can remain in host-side history.
  - `evicted` is an internal Host Bridge log/UI event, not something adapters need to send.

## Proposed USB Device Protocol

Proposed on 2026-05-29 and accepted by user:

- Host Bridge keeps the local API JSON-based for humans and adapters.
- Device protocol should be USB HID fixed-size reports.
- Product path:
  - USB HID output report.
  - Fixed-size binary frame, initially 64 bytes.
  - No user-facing serial port required.
- Development path:
  - Optional USB CDC serial debug console in development firmware.
  - CDC is for logs/manual testing, not the primary product protocol.
- Avoid vendor-specific bulk endpoints for the first version because six status lights do not need that complexity.

Proposed 64-byte display frame:

- `magic[2]`: `TL`.
- `version`: protocol version.
- `seq`: incrementing frame number.
- `brightness`: global brightness, `0..255`.
- `flags`: bitfield for global display options.
- `slots[6]`: each slot carries `state`, `anim`, `intensity`, `age`, `label_hash`, and reserved bytes.
- `crc8`: lightweight frame check.
- The firmware owns the default state palette. Host-side RGB overrides can be added later as an extension.

Rationale:

- HID avoids COM-port naming and serial-driver friction.
- Fixed binary reports are simple for firmware.
- The Host Bridge can still expose human-readable JSON over HTTP/WebSocket.

## Proposed Firmware Rendering Model

Proposed on 2026-05-29 and accepted by user:

- Host Bridge sends slot states when the FIFO or session status changes.
- Host Bridge does not stream every animation frame.
- Firmware calculates animation curves locally.
- Firmware updates the LED driver at a steady frame rate.

State behaviors:

- `running`: cyan/blue, continuous slow breathing.
- `approval`: amber, continuous attention pulse.
- `done`: green, persistent steady light.
- `error`: red, persistent steady light or slow warning pulse.
- `idle`: off.

Failsafe behavior:

- USB connected but no recent update: keep the last valid frame.
- Host heartbeat lost for a longer timeout: optionally dim all active slots to show stale data.
- Invalid frame: ignore it and keep the previous valid frame.

## Proposed Host Bridge Module Structure

Proposed on 2026-05-29 and accepted by user:

- Host Bridge should be a small local service.
- Inputs:
  - Local HTTP event API.
  - Manual test client.
  - Tool-specific adapters such as Codex, Claude, Cursor, and future local agents.
- Core:
  - Event validation.
  - Session registry.
  - FIFO queue state machine.
  - Persistence and history.
- Outputs:
  - USB HID device writer.
  - Web simulator stream.
  - Debug REST API.
  - Logs.

Design rules:

- Adapters are disposable and translate tool-specific signals into normalized events.
- FIFO core is durable and tested independently.
- Outputs are replaceable, so the same six-slot model can drive a simulator before hardware exists.

Suggested repository areas:

- `host/`: Bridge service, API, FIFO core, adapters, and simulator connection.
- `firmware/`: RP2040 firmware, HID receive, animation renderer, and LED driver code.
- `hardware/`: PCB, symbols/footprints, enclosure notes, and manufacturing outputs.

## Proposed Automation Pipeline

Proposed on 2026-05-29 and accepted by user:

Goal:

- Build an AI-assisted design pipeline with repeatable checks.
- Avoid treating hardware generation as blind one-click output.
- Every generated artifact must pass a verification gate before it becomes a design baseline.

Pipeline stages:

- Spec:
  - Requirements.
  - State semantics.
  - Six-slot mapping.
  - Selected components.
- Schematic:
  - USB-C input.
  - RP2040-class MCU.
  - LP5024-class RGB LED driver.
  - Power, ESD/protection, debug/programming pads.
- PCB:
  - Board outline.
  - LED placement.
  - Diffuser and light-isolation assumptions.
  - Routing and DRC.
- Firmware:
  - HID receive.
  - Renderer.
  - LP5024-class driver.
- Host:
  - Local API.
  - FIFO model.
  - Simulator.
  - USB HID writer.

Verification gates:

- Hardware:
  - Electrical rule check.
  - PCB design rule check.
  - BOM completeness.
  - Footprint presence.
  - USB/power review checklist.
- Software:
  - FIFO state-machine tests.
  - API schema tests.
  - HID frame encoder tests.
  - Firmware renderer tests.
  - Simulator screenshot checks.

Proposed first automation milestone:

- Create a repo skeleton with docs, host model tests, browser simulator, hardware notes, and component decision records.
- Do not start PCB layout until the six-slot logic and simulator are executable and testable.

## Execution Checkpoint - 2026-05-29

- User selected Subagent-Driven execution.
- Corrected the local simulation plan so `cleared` removes a slot, shifts later visible sessions left, and leaves the newest-side slot idle.
- Next step is an isolated implementation worktree for the local software/simulator milestone.

## Implementation Checkpoint - 2026-05-29

- Created `feature/local-simulation-foundation` in `.worktrees/local-simulation-foundation`.
- Completed and pushed the project skeleton with a Windows Node runner.
- Completed and pushed the six-slot FIFO model:
  - New sessions enter the newest/right slot.
  - Full queues evict the oldest/leftmost slot.
  - `cleared` shifts later sessions left and leaves the newest side idle.
  - History records effective states for defaulted transitions.
- Completed and pushed the local event schema:
  - External payload uses `session_id`.
  - Internal model uses `sessionId`.
  - Explicit `state: null` is rejected instead of silently defaulted.
- Completed and pushed the 64-byte HID display frame encoder:
  - Six 8-byte slot records.
  - Idle/unknown slots fail closed to idle rendering.
  - Empty slots carry zero label hash bytes.
- Current verification count before simulator work: 24 host tests passing.

## Simulator Interaction Checkpoint - 2026-05-29

- User selected simulator option A: click any of the six visible slots, then apply a state action to the selected slot.
- The simulator now keeps a selected slot index and exposes it in the rendered JSON state.
- State controls now operate on the selected slot instead of always operating on the newest/rightmost session:
  - `Set Running`
  - `Set Approval`
  - `Set Done`
  - `Set Error`
  - `Clear Selected`
- `Clear Selected` removes the selected visible session, shifts later sessions left, and leaves the newest-side slot idle.
- Focusable slots also support keyboard selection with Enter or Space.

## Core Display Panel Checkpoint - 2026-05-29

- The core display panel was adjusted toward the user-provided reference image:
  - Near-square display area.
  - Four lightly slanted vertical strips.
  - Rounded strip corners.
  - Left long strip slightly shorter than right long strip.
  - Two middle strips remain shorter and staggered.
- The six-session mapping is preserved:
  - Left long strip contains two slots.
  - Each middle strip contains one slot.
  - Right long strip contains two slots.

## Core Display Refinement Checkpoint - 2026-05-29

- User confirmed the simulator button logic works.
- Core display strips were refined from shared parallelogram geometry to per-strip irregular trapezoids:
  - Left long strip: short edge faces right.
  - Right long strip: short edge faces right.
  - Left middle short strip: short edge faces right.
  - Right middle short strip: short edge faces left.
- The strips were made thicker, longer, and visually softer with larger rounded radii and multi-point clipped corners.
- The change remains limited to the simulator's core display panel; session logic and controls are unchanged.

## Core Display Correction Checkpoint - 2026-05-29

- User caught that the right middle short strip was visually crooked.
- Root cause:
  - The strip had an explicit `rotate(1deg)`.
  - Its short-left trapezoid points also shifted the top and bottom centers.
- Correction:
  - Removed rotation from the right middle short strip.
  - Rebalanced the short-left trapezoid points so the strip stays upright while preserving a left-facing short edge.
  - Added a simulator style regression test for the upright right middle strip.

## Host Bridge Checkpoint - 2026-05-29

- User approved Host Bridge option A as the next milestone.
- Added a local dependency-free Node Host Bridge:
  - `POST /v1/events` accepts normalized session events.
  - `GET /v1/slots` returns the current six-slot snapshot.
  - `GET /v1/stream` streams slot snapshots with Server-Sent Events.
- Added CORS headers so the static `file://` simulator can talk to `localhost:8787`.
- Added CLI entry points:
  - `host/src/server-cli.js` starts the service on `127.0.0.1:8787`.
  - `host/src/demo-client.js` sends a repeatable demo event sequence.
- Updated the simulator:
  - It listens to the Host Bridge stream when available.
  - Manual buttons post events to the Host Bridge when connected.
  - If the service is unavailable, the existing in-browser manual logic remains available.
- Still out of scope:
  - Real USB HID writing.
  - Real AI-tool adapters.
  - Firmware and PCB work.

## Adapter Foundation Checkpoint - 2026-05-29

- User approved Adapter Foundation option A.
- Added a reusable event client for sending normalized events to the Host Bridge.
- Added a dependency-free event CLI:
  - `started` sends a running `started` event.
  - `running` and `approval` send `state_changed`.
  - `done` sends `ended` with `outcome: success`.
  - `error` sends `ended` with `outcome: error`.
  - `cleared` sends `cleared`.
- Added `docs/adapters/contract.md` so future Codex, Claude, Cursor, or local-agent adapters share one event contract.
- This milestone still avoids parsing real tool logs; it creates the stable adapter input surface first.

## Process Adapter Checkpoint - 2026-05-30

- User approved generic process adapter option A as the next local-only integration step.
- Added a dependency-free process runner:
  - Sends `started` before child process launch.
  - Sends `ended` with `outcome: success` for exit code `0`.
  - Sends `ended` with `outcome: error` for non-zero exits or spawn failure.
  - Keeps the child command running even if TellMeLight event delivery fails.
- Added `host/src/process-cli.js` as the `tml-run` command surface:
  - Wrapper flags are parsed before `--`.
  - Child command and arguments are passed after `--`.
  - `--source`, `--id`, `--title`, `--url`, and `--cwd` are supported.
- This creates a practical bridge for local commands before any tool-specific Codex, Claude, Cursor, or IDE log parser exists.

## Windows Codex Integration Checkpoint - 2026-05-30

- User requested direct local Windows Codex integration instead of another generic wrapper layer.
- Verified the installed Codex CLI:
  - `codex-cli 0.133.0-alpha.1`.
  - VS Code ChatGPT extension Windows binary.
  - `codex doctor` passes with proxy `http://127.0.0.1:7892`.
- Verified a real Codex request:
  - `codex exec --json -C . --sandbox read-only "Reply with exactly: TellMeLight codex smoke ok"`.
  - Observed real `thread.started` JSONL with a Codex `thread_id`.
  - Observed final agent message `TellMeLight codex smoke ok`.
- Added `tml-codex`:
  - Runs `codex exec --json` for new turns.
  - Runs `codex exec resume --json` for recorded session continuation.
  - Uses Codex `thread_id` as TellMeLight `session_id`.
  - Maps Codex JSONL turn lifecycle to `running`, `approval`, `done`, and `error`.
  - Supports `TELLMELIGHT_CODEX_PROXY` and `--tml-proxy` for the Windows proxy setup.

## Rev A KiCad Hardware Checkpoint - 2026-05-30

- User installed KiCad at `E:\kicad` and requested automatic local hardware progress while away.
- Confirmed local KiCad CLI:
  - `E:\kicad\bin\kicad-cli.exe`
  - KiCad version `10.0.3`.
  - KiCad Python `pcbnew` API version `10.0`.
- Rev A hardware baseline scope:
  - USB-C wired integrated PCB.
  - RP2040-class USB MCU.
  - LP5024-class 24-channel I2C RGB LED driver in the 32-pin 4 x 4 mm VQFN/WQFN footprint class.
  - Six common-anode RGB LED zones behind four rounded trapezoid diffuser bars.
  - AP2112K-3.3-class 3V3 regulator.
  - W25Q32JVSS-class QSPI flash.
  - TPD2EUSB30-class USB ESD protection.
- The KiCad milestone must generate project files, a block-level schematic/net plan, PCB floorplan with real footprints, Rev A BOM, power-budget simulation, and KiCad CLI reports.
- Remaining review items before fabrication:
  - Pin-by-pin schematic signoff.
  - Final routing and USB layout review.
  - Exact RGB LED optical sample decision.
  - Enclosure and diffuser CAD.
  - PCB vendor DFM rules for QFN/VQFN assembly.

## Rev A1 JLC Fabrication Candidate Checkpoint - 2026-05-30

- User wants the next hardware phase to target likely JLC/JLCPCB fabrication and assembly.
- User does not have soldering tools, so Rev A1 should avoid any assumed hand-soldering.
- User prefers a more integrated, polished, technology-forward hardware approach.
- Rev A1 selected the high-integration path:
  - 4-layer PCB by default.
  - Double-sided SMT assembly by default.
  - Front side kept mostly optical with six RGB emitters.
  - Back side carries RP2040, LP5024, USB-C, flash, regulator, ESD, passives, and debug pads.
  - SWD header direction changes from visible pin header to pogo/test pads.
- Component direction remains RP2040 + LP5024 because it is still the most product-like architecture.
- JLC candidate parts were recorded for the main active/mechanical components:
  - RP2040: `C2040`.
  - LP5024RSMR: `C427525`.
  - W25Q32JVSSIQ: `C82344`.
  - AP2112K-3.3TRG1: `C51118`.
  - TPD2EUSB30DRTR: `C94934`.
  - HRO TYPE-C-31-M-12: `C165948`.
  - S4-3528RGBTA-A common-anode RGB LED: `C2827321`.
- Next work item is a Rev A1 implementation plan and generated KiCad/BOM artifacts.

## Rev A1 Generated Hardware Checkpoint - 2026-05-30

- Added the Rev A1 implementation plan and generated hardware assets.
- Created `hardware/kicad/tellmelight_rev_a1/` as a separate KiCad project so Rev A remains preserved.
- Generated a 4-layer PCB floorplan:
  - Front side holds the six RGB emitters and diffuser alignment marks.
  - Back side holds RP2040, LP5024, flash, regulator, USB-C, ESD, passives, buttons, and test pads.
  - SWD moved from a through-hole header direction to pogo/test pads.
- Generated Rev A1 manufacturing documents:
  - `hardware/bom/rev_a1_bom.csv`.
  - `hardware/bom/rev_a1_jlc_sourcing.csv`.
  - `hardware/notes/rev-a1-jlc-readiness.md`.
  - `hardware/simulation/rev_a1_power_budget.md`.
- KiCad checks passed:
  - ERC: 0 violations.
  - DRC: 0 violations and 0 unconnected items.
- Exported Rev A1 Gerbers, drill, position data, STEP, PCB PDF/SVG, schematic PDF/SVG, and top/bottom PNG renders.
- Remaining order blockers:
  - Pin-by-pin schematic still needs fabrication signoff.
  - RGB LED pinout must be verified against the final JLC selected part.
  - USB-C mechanical/shell grounding and LP5024 exposed-pad stencil need review before ordering.

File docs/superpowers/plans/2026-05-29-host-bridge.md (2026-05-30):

# Host Bridge Implementation Plan

> **For agentic workers:** REQUIRED SUB-SKILL: Use superpowers:subagent-driven-development (recommended) or superpowers:executing-plans to implement this plan task-by-task. Steps use checkbox (`- [ ]`) syntax for tracking.

**Goal:** Build a local Host Bridge that accepts AI session events, exposes the current six-slot state, and streams updates to the simulator.

**Architecture:** The service is a dependency-free Node layer around the existing FIFO and schema modules. `bridge-state` owns mutable in-memory state and subscriber notifications; `http-server` maps local HTTP/SSE routes to the bridge; the simulator consumes the stream but keeps manual fallback behavior.

**Tech Stack:** JavaScript ES modules, Node built-in `http`, Node built-in `node:test`, browser `EventSource`, browser `fetch`, static HTML/CSS/JS.

---

## File Structure

- Create `host/src/bridge-state.js`: bridge model wrapper, slot snapshots, event application, subscriber notification.
- Create `host/src/http-server.js`: dependency-free HTTP request handler, JSON routes, SSE stream, CORS for `file://` simulator use.
- Create `host/src/server-cli.js`: starts the Host Bridge on `127.0.0.1:8787`.
- Create `host/src/demo-client.js`: sends a repeatable local demo event sequence.
- Create `host/test/bridge-state.test.js`: tests snapshots, event application, and subscribers.
- Create `host/test/http-server.test.js`: tests `GET /v1/slots`, `POST /v1/events`, errors, and SSE updates.
- Modify `simulator/app.js`: connect to Host Bridge stream, send manual controls to the bridge when available, keep local fallback.
- Modify `host/test/simulator-assets.test.js`: assert simulator contains bridge connection and fallback hooks.
- Modify `package.json`: add `host` and `demo` scripts.
- Modify `README.md`: document local Host Bridge commands.
- Modify `docs/superpowers/brainstorm/2026-05-29-tellmelight-progress.md`: record the milestone checkpoint.

## Task 1: Bridge State Module

**Files:**
- Create: `host/src/bridge-state.js`
- Test: `host/test/bridge-state.test.js`

- [ ] **Step 1: Write failing bridge state tests**

Create `host/test/bridge-state.test.js`:

```js
import assert from 'node:assert/strict';
import test from 'node:test';
import { createBridge } from '../src/bridge-state.js';

test('bridge snapshot exposes six idle slots', () => {
  const bridge = createBridge();

  assert.equal(bridge.snapshot().revision, 0);
  assert.deepEqual(
    bridge.snapshot().slots.map((slot) => slot.state),
    ['idle', 'idle', 'idle', 'idle', 'idle', 'idle'],
  );
  assert.deepEqual(
    bridge.snapshot().slots.map((slot) => slot.id),
    [null, null, null, null, null, null],
  );
});

test('bridge applies normalized event payloads through the FIFO core', () => {
  const bridge = createBridge();

  const snapshot = bridge.applyEventPayload({
    source: 'manual',
    session_id: 's1',
    event: 'started',
    title: 'First local session',
  });

  assert.equal(snapshot.revision, 1);
  assert.equal(snapshot.slots[5].id, 's1');
  assert.equal(snapshot.slots[5].source, 'manual');
  assert.equal(snapshot.slots[5].state, 'running');
  assert.equal(snapshot.slots[5].title, 'First local session');
});

test('bridge notifies subscribers immediately and after changes', () => {
  const bridge = createBridge();
  const revisions = [];

  const unsubscribe = bridge.subscribe((snapshot) => {
    revisions.push(snapshot.revision);
  });
  bridge.applyEventPayload({ source: 'manual', session_id: 's1', event: 'started' });
  unsubscribe();
  bridge.applyEventPayload({ source: 'manual', session_id: 's2', event: 'started' });

  assert.deepEqual(revisions, [0, 1]);
});
```

- [ ] **Step 2: Run bridge state tests to verify they fail**

Run:

```powershell
powershell -ExecutionPolicy Bypass -File tools/run-node.ps1 --test host/test/bridge-state.test.js
```

Expected: FAIL because `host/src/bridge-state.js` does not exist.

- [ ] **Step 3: Implement bridge state**

Create `host/src/bridge-state.js` with `createBridge()`, `snapshot()`, `applyEventPayload(payload)`, and `subscribe(listener)`. It should use `normalizeEvent()` and `applyEvent()` from existing modules.

- [ ] **Step 4: Run bridge state tests to verify they pass**

Run:

```powershell
powershell -ExecutionPolicy Bypass -File tools/run-node.ps1 --test host/test/bridge-state.test.js
```

Expected: PASS.

- [ ] **Step 5: Commit bridge state**

```bash
git add host/src/bridge-state.js host/test/bridge-state.test.js
git commit -m "feat: add host bridge state"
```

## Task 2: HTTP And SSE Server

**Files:**
- Create: `host/src/http-server.js`
- Test: `host/test/http-server.test.js`

- [ ] **Step 1: Write failing server tests**

Create tests for:

- `GET /v1/slots` returns six idle slots.
- `POST /v1/events` returns 202 and updates slot 6.
- Invalid JSON returns 400 with `error`.
- `GET /v1/stream` sends an initial `event: slots` frame and another frame after a POST.

- [ ] **Step 2: Run server tests to verify they fail**

Run:

```powershell
powershell -ExecutionPolicy Bypass -File tools/run-node.ps1 --test host/test/http-server.test.js
```

Expected: FAIL because `host/src/http-server.js` does not exist.

- [ ] **Step 3: Implement HTTP server**

Create `createHostBridgeServer({ bridge = createBridge() } = {})`. It must:

- Add `Access-Control-Allow-Origin: *`.
- Handle `OPTIONS` with 204.
- Return JSON for `GET /v1/slots`.
- Read and parse JSON for `POST /v1/events`.
- Return 400 JSON on parse or validation errors.
- Stream SSE for `GET /v1/stream`.
- Return 404 JSON for unknown routes.

- [ ] **Step 4: Run server tests to verify they pass**

Run:

```powershell
powershell -ExecutionPolicy Bypass -File tools/run-node.ps1 --test host/test/http-server.test.js
```

Expected: PASS.

- [ ] **Step 5: Commit server**

```bash
git add host/src/http-server.js host/test/http-server.test.js
git commit -m "feat: serve host bridge API"
```

## Task 3: CLI And Demo Client

**Files:**
- Create: `host/src/server-cli.js`
- Create: `host/src/demo-client.js`
- Modify: `package.json`
- Modify: `README.md`

- [ ] **Step 1: Add commands**

Add scripts:

```json
"host": "node host/src/server-cli.js",
"demo": "node host/src/demo-client.js"
```

- [ ] **Step 2: Implement CLI**

`server-cli.js` starts the server on `127.0.0.1` and `TELLMELIGHT_PORT || 8787`.

- [ ] **Step 3: Implement demo client**

`demo-client.js` sends a repeatable event sequence to `TELLMELIGHT_URL || http://127.0.0.1:8787`.

- [ ] **Step 4: Verify commands**

Run:

```powershell
powershell -ExecutionPolicy Bypass -File tools/run-node.ps1 --test host/test/*.test.js
```

Expected: PASS.

- [ ] **Step 5: Commit CLI and docs**

```bash
git add host/src/server-cli.js host/src/demo-client.js package.json README.md
git commit -m "feat: add host bridge commands"
```

## Task 4: Simulator Bridge Connection

**Files:**
- Modify: `simulator/app.js`
- Modify: `host/test/simulator-assets.test.js`

- [ ] **Step 1: Write failing simulator asset tests**

Extend `host/test/simulator-assets.test.js` to assert:

- `EventSource` is used.
- `http://localhost:8787/v1/stream` appears.
- `POST` and `/v1/events` appear.
- `applyBridgeSnapshot` and `fallbackToLocal` appear.

- [ ] **Step 2: Run simulator asset tests to verify they fail**

Run:

```powershell
powershell -ExecutionPolicy Bypass -File tools/run-node.ps1 --test host/test/simulator-assets.test.js
```

Expected: FAIL until simulator bridge connection code exists.

- [ ] **Step 3: Implement simulator connection**

Change `simulator/app.js` so:

- It opens `new EventSource('http://localhost:8787/v1/stream')`.
- Incoming `slots` events call `applyBridgeSnapshot(snapshot)` and render.
- Manual controls call `POST /v1/events` when the bridge is connected.
- Failed connection or failed POST calls `fallbackToLocal()`.
- Existing manual behavior remains available offline.

- [ ] **Step 4: Run simulator asset tests**

Run:

```powershell
powershell -ExecutionPolicy Bypass -File tools/run-node.ps1 --test host/test/simulator-assets.test.js
```

Expected: PASS.

- [ ] **Step 5: Commit simulator connection**

```bash
git add simulator/app.js host/test/simulator-assets.test.js
git commit -m "feat: connect simulator to host bridge"
```

## Task 5: Final Verification And Progress Record

**Files:**
- Modify: `docs/superpowers/brainstorm/2026-05-29-tellmelight-progress.md`

- [ ] **Step 1: Record progress checkpoint**

Add a Host Bridge checkpoint with the accepted API and simulator fallback behavior.

- [ ] **Step 2: Run full tests**

Run:

```powershell
powershell -ExecutionPolicy Bypass -File tools/run-node.ps1 --test host/test/*.test.js
```

Expected: all tests pass.

- [ ] **Step 3: Check whitespace and status**

Run:

```bash
git diff --check
git status --short
```

Expected: no whitespace errors; only intended files modified.

- [ ] **Step 4: Commit progress record**

```bash
git add docs/superpowers/brainstorm/2026-05-29-tellmelight-progress.md
git commit -m "docs: record host bridge milestone"
```

- [ ] **Step 5: Push checkpoint**

Run:

```bash
git push origin feature/local-simulation-foundation
```

Expected: branch pushes successfully.

## Self-Review

- Spec coverage:
  - `POST /v1/events`: Task 2.
  - `GET /v1/slots`: Task 2.
  - `GET /v1/stream`: Task 2.
  - Manual demo client: Task 3.
  - Simulator fallback: Task 4.
  - Progress recording: Task 5.
- Placeholder scan: no incomplete implementation slots remain.
- Type consistency:
  - External payload remains `session_id`.
  - Internal model remains `sessionId`.
  - Public snapshot uses `id` for simulator compatibility.

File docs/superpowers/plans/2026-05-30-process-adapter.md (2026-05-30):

# Process Adapter Implementation Plan

> **For agentic workers:** REQUIRED SUB-SKILL: Use superpowers:subagent-driven-development (recommended) or superpowers:executing-plans to implement this plan task-by-task. Steps use checkbox (`- [ ]`) syntax for tracking.

**Goal:** Add a generic process wrapper that runs any local command while reporting started, done, and error events to the Host Bridge.

**Architecture:** `process-runner` owns child process execution and event ordering; `process-cli` parses wrapper flags and delegates to the runner. The existing `event-client` remains the only HTTP delivery layer, and Host Bridge remains the owner of validation and FIFO state.

**Tech Stack:** JavaScript ES modules, Node built-in `child_process`, Node built-in `node:test`, dependency-free CLI parsing, Markdown docs.

---

## File Structure

- Create `host/src/process-runner.js`: exports `runProcessWithEvents()` and child-process event mapping helpers.
- Create `host/src/process-cli.js`: exports `parseProcessCliArgs()` and runs as a CLI.
- Create `host/test/process-runner.test.js`: tests event ordering, exit-code mapping, and event-send failure behavior with fake spawn/send functions.
- Create `host/test/process-cli.test.js`: tests CLI parsing, `--` separator handling, and auto ID behavior.
- Modify `host/test/host-commands.test.js`: asserts package exposes the process wrapper command and script assets exist.
- Modify `host/test/docs.test.js`: asserts process adapter docs exist.
- Modify `package.json`: adds `tml-run` script.
- Modify `README.md`: adds process wrapper examples.
- Modify `docs/adapters/contract.md`: adds process wrapper section.
- Modify `docs/superpowers/brainstorm/2026-05-29-tellmelight-progress.md`: records Process Adapter checkpoint.

## Task 1: Process Runner Core

**Files:**
- Create: `host/src/process-runner.js`
- Test: `host/test/process-runner.test.js`

- [ ] **Step 1: Write failing runner tests**

Create tests for:

- Sends `started` before spawning the child process.
- Sends `ended` with `outcome: "success"` when exit code is `0`.
- Sends `ended` with `outcome: "error"` when exit code is non-zero.
- Continues to spawn and returns the child exit code when the initial TellMeLight event send fails.

- [ ] **Step 2: Run runner tests to verify they fail**

Run:

```powershell
powershell -ExecutionPolicy Bypass -File tools/run-node.ps1 --test host/test/process-runner.test.js
```

Expected: FAIL because `host/src/process-runner.js` does not exist.

- [ ] **Step 3: Implement runner**

Create `runProcessWithEvents(options)`.

It must accept:

- `command`
- `args`
- `sessionId`
- `source`
- `title`
- `baseUrl`
- optional `sendEventImpl`
- optional `spawnImpl`
- optional `stdio`

It must return the child exit code.

- [ ] **Step 4: Run runner tests**

Run:

```powershell
powershell -ExecutionPolicy Bypass -File tools/run-node.ps1 --test host/test/process-runner.test.js
```

Expected: PASS.

- [ ] **Step 5: Commit runner**

```bash
git add host/src/process-runner.js host/test/process-runner.test.js
git commit -m "feat: add generic process runner"
```

## Task 2: Process CLI

**Files:**
- Create: `host/src/process-cli.js`
- Test: `host/test/process-cli.test.js`
- Modify: `host/test/host-commands.test.js`
- Modify: `package.json`

- [ ] **Step 1: Write failing CLI tests**

Create tests for:

- Parses `--source codex --id s1 --title Build -- echo ok`.
- Uses `process` as default source.
- Generates a session ID when `--id` is omitted.
- Uses the command as default title when `--title` is omitted.
- Throws when `--` separator is missing.
- Throws when no command follows `--`.

- [ ] **Step 2: Run CLI tests to verify they fail**

Run:

```powershell
powershell -ExecutionPolicy Bypass -File tools/run-node.ps1 --test host/test/process-cli.test.js
```

Expected: FAIL because `host/src/process-cli.js` does not exist.

- [ ] **Step 3: Implement CLI**

Create:

- `parseProcessCliArgs(args, options)`
- `runProcessCli(args)`

Add package script:

```json
"tml-run": "node host/src/process-cli.js"
```

- [ ] **Step 4: Run CLI and asset tests**

Run:

```powershell
powershell -ExecutionPolicy Bypass -File tools/run-node.ps1 --test host/test/process-cli.test.js host/test/host-commands.test.js
```

Expected: PASS.

- [ ] **Step 5: Commit CLI**

```bash
git add host/src/process-cli.js host/test/process-cli.test.js host/test/host-commands.test.js package.json
git commit -m "feat: add process adapter CLI"
```

## Task 3: Documentation And Progress

**Files:**
- Modify: `docs/adapters/contract.md`
- Modify: `README.md`
- Modify: `host/test/docs.test.js`
- Modify: `docs/superpowers/brainstorm/2026-05-29-tellmelight-progress.md`

- [ ] **Step 1: Write failing docs tests**

Extend docs tests to assert:

- `docs/adapters/contract.md` mentions `process-cli.js`.
- It contains `tml-run`.
- It contains `--source`, `--id`, and `--`.

- [ ] **Step 2: Run docs tests to verify they fail**

Run:

```powershell
powershell -ExecutionPolicy Bypass -File tools/run-node.ps1 --test host/test/docs.test.js
```

Expected: FAIL until docs are updated.

- [ ] **Step 3: Update docs**

Add process wrapper examples to README and adapter contract. Record the Process Adapter checkpoint in the Superpowers progress log.

- [ ] **Step 4: Run docs tests**

Run:

```powershell
powershell -ExecutionPolicy Bypass -File tools/run-node.ps1 --test host/test/docs.test.js
```

Expected: PASS.

- [ ] **Step 5: Commit docs**

```bash
git add docs/adapters/contract.md README.md host/test/docs.test.js docs/superpowers/brainstorm/2026-05-29-tellmelight-progress.md
git commit -m "docs: document process adapter"
```

## Task 4: Final Verification

**Files:**
- No new files.

- [ ] **Step 1: Run full tests**

Run:

```powershell
powershell -ExecutionPolicy Bypass -File tools/run-node.ps1 --test host/test/*.test.js
```

Expected: all tests pass.

- [ ] **Step 2: Run whitespace check**

Run:

```bash
git diff --check
```

Expected: no output.

- [ ] **Step 3: Run local process wrapper smoke test**

Start a temporary Host Bridge, run:

```powershell
powershell -ExecutionPolicy Bypass -File tools/run-node.ps1 host/src/process-cli.js --source smoke --id process-smoke --title "Process smoke" -- powershell -Command "exit 0"
```

Expected: command exits `0` and `/v1/slots` contains `process-smoke` as done.

- [ ] **Step 4: Push branch**

Run:

```bash
git push origin feature/local-simulation-foundation
```

Expected: branch pushes successfully.

## Self-Review

- Spec coverage:
  - Started before command: Task 1.
  - Done/error by exit code: Task 1.
  - Event-send failure is non-blocking: Task 1.
  - CLI flags and `--` separator: Task 2.
  - README and adapter contract examples: Task 3.
- Placeholder scan: no incomplete implementation slots remain.
- Type consistency:
  - CLI flag uses `--id`.
  - Event payload uses `session_id`.
  - Default source is `process`.

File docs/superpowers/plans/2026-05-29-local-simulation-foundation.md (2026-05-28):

# Local Simulation Foundation Implementation Plan

> **For agentic workers:** REQUIRED SUB-SKILL: Use superpowers:subagent-driven-development (recommended) or superpowers:executing-plans to implement this plan task-by-task. Steps use checkbox (`- [ ]`) syntax for tracking.

**Goal:** Build the local-only TellMeLight foundation: FIFO session model, event schema, HID frame encoder, static browser simulator, and hardware decision notes.

**Architecture:** The first implementation milestone is software-only. A dependency-free Node.js core models normalized session events and six display slots; a static browser simulator renders the refined four-bar, six-zone layout; hardware work is represented as decision records and notes, not PCB files.

**Tech Stack:** JavaScript ES modules, Node.js built-in `node:test`, PowerShell runner for Windows, static HTML/CSS/JS simulator, Markdown docs.

---

## File Structure

- `package.json`: project metadata and script commands.
- `tools/run-node.ps1`: Windows-friendly Node launcher that uses global Node when available and falls back to Codex-bundled Node on this machine.
- `host/src/states.js`: state constants, slot constants, and color/animation defaults.
- `host/src/fifo.js`: pure FIFO state machine for session events.
- `host/src/schema.js`: validation and normalization for local API events.
- `host/src/hid-frame.js`: fixed-size 64-byte HID frame encoder.
- `host/test/fifo.test.js`: FIFO behavior tests.
- `host/test/schema.test.js`: local API schema tests.
- `host/test/hid-frame.test.js`: HID frame encoding tests.
- `simulator/index.html`: static simulator shell.
- `simulator/styles.css`: simulator visual styling for the refined four-bar face.
- `simulator/app.js`: browser-side rendering and sample event playback.
- `host/test/simulator-assets.test.js`: static simulator asset smoke tests.
- `hardware/notes/rev-a-architecture.md`: local hardware architecture notes, no PCB files yet.
- `docs/decisions/0001-local-simulation-first.md`: decision record for software simulation before PCB layout.
- `README.md`: project overview and local commands.

## Task 1: Project Skeleton And Node Runner

**Files:**
- Create: `package.json`
- Create: `tools/run-node.ps1`
- Create: `README.md`

- [ ] **Step 1: Create package metadata**

Create `package.json`:

```json
{
  "name": "tellmelight",
  "version": "0.1.0",
  "private": true,
  "type": "module",
  "description": "Local-first design and simulation foundation for TellMeLight.",
  "scripts": {
    "test": "node --test host/test/*.test.js"
  }
}
```

- [ ] **Step 2: Create the Windows Node runner**

Create `tools/run-node.ps1`:

```powershell
param(
    [Parameter(ValueFromRemainingArguments = $true)]
    [string[]]$NodeArgs
)

$nodeCommand = Get-Command node -ErrorAction SilentlyContinue
if ($nodeCommand) {
    & $nodeCommand.Source @NodeArgs
    exit $LASTEXITCODE
}

$codexBin = Join-Path $env:LOCALAPPDATA 'OpenAI\Codex\bin'
$codexNodes = @()
if (Test-Path -LiteralPath $codexBin) {
    $codexNodes = Get-ChildItem -Path $codexBin -Recurse -Filter node.exe -ErrorAction SilentlyContinue |
        Sort-Object LastWriteTime -Descending
}

if ($codexNodes.Count -gt 0) {
    & $codexNodes[0].FullName @NodeArgs
    exit $LASTEXITCODE
}

Write-Error 'Node.js was not found. Install Node.js or run this project from a Codex environment with bundled Node.'
exit 1
```

- [ ] **Step 3: Create README with local commands**

Create `README.md`:

```markdown
# TellMeLight

TellMeLight is a USB-connected AI hardware design for visualizing local AI sessions as a persistent six-slot light queue.

Current milestone: local software simulation only. No real PCB or USB device is required.

## Local Commands

Run all tests on Windows:

```powershell
powershell -ExecutionPolicy Bypass -File tools/run-node.ps1 --test host/test/*.test.js
```

Open the static simulator:

```text
simulator/index.html
```

## Design Docs

- `docs/superpowers/specs/2026-05-29-tellmelight-design.md`
- `docs/superpowers/brainstorm/2026-05-29-tellmelight-progress.md`
```

- [ ] **Step 4: Verify Node runner**

Run:

```powershell
powershell -ExecutionPolicy Bypass -File tools/run-node.ps1 -e "console.log('node-ok')"
```

Expected: command prints `node-ok` and exits with code 0.

- [ ] **Step 5: Commit skeleton**

Run:

```bash
git add package.json tools/run-node.ps1 README.md
git commit -m "chore: add local project skeleton"
```

## Task 2: FIFO Core

**Files:**
- Create: `host/src/states.js`
- Create: `host/src/fifo.js`
- Test: `host/test/fifo.test.js`

- [ ] **Step 1: Write failing FIFO tests**

Create `host/test/fifo.test.js`:

```js
import assert from 'node:assert/strict';
import test from 'node:test';
import { createEmptyModel, applyEvent } from '../src/fifo.js';
import { STATE } from '../src/states.js';

function ids(model) {
  return model.slots.map((slot) => slot?.sessionId ?? null);
}

function states(model) {
  return model.slots.map((slot) => slot?.state ?? STATE.IDLE);
}

test('started inserts newest session into slot 6 and shifts older sessions left', () => {
  let model = createEmptyModel();

  for (const sessionId of ['s1', 's2', 's3']) {
    model = applyEvent(model, { source: 'test', sessionId, event: 'started', state: STATE.RUNNING });
  }

  assert.deepEqual(ids(model), [null, null, null, 's1', 's2', 's3']);
  assert.deepEqual(states(model), [STATE.IDLE, STATE.IDLE, STATE.IDLE, STATE.RUNNING, STATE.RUNNING, STATE.RUNNING]);
});

test('seventh started event evicts slot 1 and appends newest session', () => {
  let model = createEmptyModel();

  for (const sessionId of ['s1', 's2', 's3', 's4', 's5', 's6', 's7']) {
    model = applyEvent(model, { source: 'test', sessionId, event: 'started', state: STATE.RUNNING });
  }

  assert.deepEqual(ids(model), ['s2', 's3', 's4', 's5', 's6', 's7']);
  assert.equal(model.history.at(-1).type, 'evicted');
  assert.equal(model.history.at(-1).sessionId, 's1');
});

test('state_changed updates an existing session in place', () => {
  let model = createEmptyModel();
  model = applyEvent(model, { source: 'test', sessionId: 's1', event: 'started', state: STATE.RUNNING });
  model = applyEvent(model, { source: 'test', sessionId: 's1', event: 'state_changed', state: STATE.APPROVAL });

  assert.deepEqual(ids(model), [null, null, null, null, null, 's1']);
  assert.deepEqual(states(model), [STATE.IDLE, STATE.IDLE, STATE.IDLE, STATE.IDLE, STATE.IDLE, STATE.APPROVAL]);
});

test('state_changed for unknown session creates a new visible session', () => {
  let model = createEmptyModel();
  model = applyEvent(model, { source: 'test', sessionId: 'late', event: 'state_changed', state: STATE.APPROVAL });

  assert.deepEqual(ids(model), [null, null, null, null, null, 'late']);
  assert.deepEqual(states(model), [STATE.IDLE, STATE.IDLE, STATE.IDLE, STATE.IDLE, STATE.IDLE, STATE.APPROVAL]);
});

test('ended keeps session visible and maps default outcome to done', () => {
  let model = createEmptyModel();
  model = applyEvent(model, { source: 'test', sessionId: 's1', event: 'started', state: STATE.RUNNING });
  model = applyEvent(model, { source: 'test', sessionId: 's1', event: 'ended' });

  assert.deepEqual(ids(model), [null, null, null, null, null, 's1']);
  assert.equal(model.slots[5].state, STATE.DONE);
});

test('ended with error outcome keeps session visible as error', () => {
  let model = createEmptyModel();
  model = applyEvent(model, { source: 'test', sessionId: 's1', event: 'started', state: STATE.RUNNING });
  model = applyEvent(model, { source: 'test', sessionId: 's1', event: 'ended', outcome: 'error' });

  assert.equal(model.slots[5].state, STATE.ERROR);
});

test('cleared removes a session and compacts remaining sessions left', () => {
  let model = createEmptyModel();
  for (const sessionId of ['s1', 's2', 's3', 's4']) {
    model = applyEvent(model, { source: 'test', sessionId, event: 'started', state: STATE.RUNNING });
  }

  model = applyEvent(model, { source: 'test', sessionId: 's2', event: 'cleared' });

  assert.deepEqual(ids(model), [null, null, 's1', 's3', 's4', null]);
});
```

- [ ] **Step 2: Run tests to verify they fail**

Run:

```powershell
powershell -ExecutionPolicy Bypass -File tools/run-node.ps1 --test host/test/fifo.test.js
```

Expected: FAIL because `host/src/fifo.js` and `host/src/states.js` do not exist.

- [ ] **Step 3: Implement state constants**

Create `host/src/states.js`:

```js
export const SLOT_COUNT = 6;

export const STATE = Object.freeze({
  IDLE: 'idle',
  RUNNING: 'running',
  APPROVAL: 'approval',
  DONE: 'done',
  ERROR: 'error',
});

export const EVENT = Object.freeze({
  STARTED: 'started',
  STATE_CHANGED: 'state_changed',
  ENDED: 'ended',
  CLEARED: 'cleared',
});

export const ANIMATION = Object.freeze({
  OFF: 'off',
  STEADY: 'steady',
  BREATHE: 'breathe',
  PULSE: 'pulse',
  WARNING: 'warning',
});

export const STATE_RENDERING = Object.freeze({
  [STATE.IDLE]: { color: '#000000', animation: ANIMATION.OFF, intensity: 0 },
  [STATE.RUNNING]: { color: '#38bdf8', animation: ANIMATION.BREATHE, intensity: 220 },
  [STATE.APPROVAL]: { color: '#f59e0b', animation: ANIMATION.PULSE, intensity: 255 },
  [STATE.DONE]: { color: '#22c55e', animation: ANIMATION.STEADY, intensity: 220 },
  [STATE.ERROR]: { color: '#ef4444', animation: ANIMATION.WARNING, intensity: 255 },
});

export function isKnownState(state) {
  return Object.values(STATE).includes(state);
}

export function isKnownEvent(event) {
  return Object.values(EVENT).includes(event);
}
```

- [ ] **Step 4: Implement FIFO core**

Create `host/src/fifo.js`:

```js
import { EVENT, SLOT_COUNT, STATE } from './states.js';

export function createEmptyModel() {
  return {
    slots: Array.from({ length: SLOT_COUNT }, () => null),
    history: [],
    revision: 0,
  };
}

export function applyEvent(model, event) {
  const next = cloneModel(model);

  if (event.event === EVENT.CLEARED) {
    return clearSession(next, event);
  }

  const index = findSessionIndex(next.slots, event.sessionId);

  if (event.event === EVENT.STARTED) {
    if (index >= 0) {
      next.slots[index] = mergeSlot(next.slots[index], event, STATE.RUNNING);
      return bump(next, event);
    }
    return appendSession(next, event, event.state ?? STATE.RUNNING);
  }

  if (event.event === EVENT.STATE_CHANGED) {
    if (index >= 0) {
      next.slots[index] = mergeSlot(next.slots[index], event, event.state ?? next.slots[index].state);
      return bump(next, event);
    }
    return appendSession(next, event, event.state ?? STATE.RUNNING);
  }

  if (event.event === EVENT.ENDED) {
    const state = event.outcome === 'error' ? STATE.ERROR : STATE.DONE;
    if (index >= 0) {
      next.slots[index] = mergeSlot(next.slots[index], event, state);
      return bump(next, event);
    }
    return appendSession(next, event, state);
  }

  throw new Error(`Unsupported event: ${event.event}`);
}

function cloneModel(model) {
  return {
    slots: model.slots.map((slot) => (slot ? { ...slot } : null)),
    history: model.history.map((entry) => ({ ...entry })),
    revision: model.revision,
  };
}

function appendSession(model, event, state) {
  const nonEmpty = model.slots.filter(Boolean);
  if (nonEmpty.length === SLOT_COUNT) {
    const evicted = nonEmpty.shift();
    model.history.push({ type: 'evicted', sessionId: evicted.sessionId, source: evicted.source });
  }

  nonEmpty.push(createSlot(event, state));
  model.slots = leftPadWithIdle(nonEmpty);
  return bump(model, event);
}

function clearSession(model, event) {
  const index = findSessionIndex(model, event.sessionId);
  if (index < 0) {
    return bump(model, event);
  }

  model.slots = [
    ...model.slots.slice(0, index),
    ...model.slots.slice(index + 1),
    null,
  ];
  return bump(model, event);
}

function leftPadWithIdle(nonEmptySlots) {
  const emptyCount = SLOT_COUNT - nonEmptySlots.length;
  return [...Array.from({ length: emptyCount }, () => null), ...nonEmptySlots];
}

function createSlot(event, state) {
  return {
    sessionId: event.sessionId,
    source: event.source,
    state,
    title: event.title ?? '',
    updatedAt: event.time ?? new Date().toISOString(),
  };
}

function mergeSlot(slot, event, state) {
  return {
    ...slot,
    source: event.source ?? slot.source,
    state,
    title: event.title ?? slot.title,
    updatedAt: event.time ?? new Date().toISOString(),
  };
}

function findSessionIndex(slots, sessionId) {
  return slots.findIndex((slot) => slot?.sessionId === sessionId);
}

function bump(model, event) {
  model.revision += 1;
  model.history.push({ type: event.event, sessionId: event.sessionId, state: event.state ?? null });
  return model;
}
```

- [ ] **Step 5: Run FIFO tests to verify they pass**

Run:

```powershell
powershell -ExecutionPolicy Bypass -File tools/run-node.ps1 --test host/test/fifo.test.js
```

Expected: PASS for 7 tests.

- [ ] **Step 6: Commit FIFO core**

Run:

```bash
git add host/src/states.js host/src/fifo.js host/test/fifo.test.js
git commit -m "feat: add FIFO session model"
```

## Task 3: Local API Event Schema

**Files:**
- Create: `host/src/schema.js`
- Test: `host/test/schema.test.js`

- [ ] **Step 1: Write failing schema tests**

Create `host/test/schema.test.js`:

```js
import assert from 'node:assert/strict';
import test from 'node:test';
import { normalizeEvent } from '../src/schema.js';
import { EVENT, STATE } from '../src/states.js';

test('normalizeEvent converts snake_case session_id into internal sessionId', () => {
  const event = normalizeEvent({
    source: 'codex',
    session_id: 'abc123',
    event: 'started',
    state: 'running',
    title: 'Build firmware',
    time: '2026-05-29T00:00:00+08:00',
  });

  assert.deepEqual(event, {
    source: 'codex',
    sessionId: 'abc123',
    event: EVENT.STARTED,
    state: STATE.RUNNING,
    title: 'Build firmware',
    time: '2026-05-29T00:00:00+08:00',
    outcome: undefined,
  });
});

test('normalizeEvent defaults started state to running', () => {
  const event = normalizeEvent({
    source: 'manual',
    session_id: 's1',
    event: 'started',
  });

  assert.equal(event.state, STATE.RUNNING);
});

test('normalizeEvent accepts ended without state', () => {
  const event = normalizeEvent({
    source: 'manual',
    session_id: 's1',
    event: 'ended',
  });

  assert.equal(event.event, EVENT.ENDED);
  assert.equal(event.state, undefined);
});

test('normalizeEvent rejects unknown states', () => {
  assert.throws(
    () => normalizeEvent({ source: 'manual', session_id: 's1', event: 'started', state: 'paused' }),
    /Unsupported state/
  );
});

test('normalizeEvent rejects missing session_id', () => {
  assert.throws(
    () => normalizeEvent({ source: 'manual', event: 'started', state: 'running' }),
    /session_id/
  );
});

test('normalizeEvent rejects unknown events', () => {
  assert.throws(
    () => normalizeEvent({ source: 'manual', session_id: 's1', event: 'renamed' }),
    /Unsupported event/
  );
});
```

- [ ] **Step 2: Run schema tests to verify they fail**

Run:

```powershell
powershell -ExecutionPolicy Bypass -File tools/run-node.ps1 --test host/test/schema.test.js
```

Expected: FAIL because `host/src/schema.js` does not exist.

- [ ] **Step 3: Implement schema normalization**

Create `host/src/schema.js`:

```js
import { EVENT, STATE, isKnownEvent, isKnownState } from './states.js';

export function normalizeEvent(payload) {
  if (!payload || typeof payload !== 'object') {
    throw new Error('Event payload must be an object');
  }

  const source = readRequiredString(payload, 'source');
  const sessionId = readRequiredString(payload, 'session_id');
  const event = readRequiredString(payload, 'event');

  if (!isKnownEvent(event)) {
    throw new Error(`Unsupported event: ${event}`);
  }

  const state = payload.state ?? defaultStateForEvent(event);
  if (state !== undefined && !isKnownState(state)) {
    throw new Error(`Unsupported state: ${state}`);
  }

  const outcome = payload.outcome === undefined ? undefined : String(payload.outcome);

  return {
    source,
    sessionId,
    event,
    state,
    title: payload.title === undefined ? '' : String(payload.title),
    time: payload.time === undefined ? new Date().toISOString() : String(payload.time),
    outcome,
  };
}

function readRequiredString(payload, key) {
  const value = payload[key];
  if (typeof value !== 'string' || value.trim() === '') {
    throw new Error(`Field ${key} is required`);
  }
  return value.trim();
}

function defaultStateForEvent(event) {
  if (event === EVENT.STARTED) return STATE.RUNNING;
  return undefined;
}
```

- [ ] **Step 4: Run schema tests to verify they pass**

Run:

```powershell
powershell -ExecutionPolicy Bypass -File tools/run-node.ps1 --test host/test/schema.test.js
```

Expected: PASS for 6 tests.

- [ ] **Step 5: Run FIFO and schema tests together**

Run:

```powershell
powershell -ExecutionPolicy Bypass -File tools/run-node.ps1 --test host/test/fifo.test.js host/test/schema.test.js
```

Expected: PASS for all tests.

- [ ] **Step 6: Commit schema**

Run:

```bash
git add host/src/schema.js host/test/schema.test.js
git commit -m "feat: add local event schema"
```

## Task 4: HID Frame Encoder

**Files:**
- Create: `host/src/hid-frame.js`
- Test: `host/test/hid-frame.test.js`

- [ ] **Step 1: Write failing HID frame tests**

Create `host/test/hid-frame.test.js`:

```js
import assert from 'node:assert/strict';
import test from 'node:test';
import { encodeDisplayFrame } from '../src/hid-frame.js';
import { STATE } from '../src/states.js';

test('encodeDisplayFrame returns a 64-byte frame with TellMeLight magic', () => {
  const frame = encodeDisplayFrame({
    seq: 7,
    brightness: 128,
    slots: [{ sessionId: 'a', state: STATE.RUNNING }],
  });

  assert.equal(frame.length, 64);
  assert.equal(String.fromCharCode(frame[0], frame[1]), 'TL');
  assert.equal(frame[2], 1);
  assert.equal(frame[3], 7);
  assert.equal(frame[4], 128);
});

test('encodeDisplayFrame encodes slot state and animation intent', () => {
  const frame = encodeDisplayFrame({
    seq: 1,
    brightness: 255,
    slots: [
      { sessionId: 'a', state: STATE.RUNNING },
      { sessionId: 'b', state: STATE.APPROVAL },
      { sessionId: 'c', state: STATE.DONE },
      { sessionId: 'd', state: STATE.ERROR },
      null,
      null,
    ],
  });

  assert.equal(frame[8], 1);
  assert.equal(frame[9], 2);
  assert.equal(frame[16], 2);
  assert.equal(frame[17], 3);
  assert.equal(frame[24], 3);
  assert.equal(frame[25], 1);
  assert.equal(frame[32], 4);
  assert.equal(frame[33], 4);
  assert.equal(frame[40], 0);
  assert.equal(frame[48], 0);
});

test('encodeDisplayFrame appends a deterministic crc8 byte', () => {
  const first = encodeDisplayFrame({ seq: 1, brightness: 200, slots: [] });
  const second = encodeDisplayFrame({ seq: 1, brightness: 200, slots: [] });

  assert.equal(first[63], second[63]);
  assert.notEqual(first[63], 0);
});

test('encodeDisplayFrame clamps brightness and sequence values to one byte', () => {
  const frame = encodeDisplayFrame({ seq: 999, brightness: 999, slots: [] });

  assert.equal(frame[3], 255);
  assert.equal(frame[4], 255);
});
```

- [ ] **Step 2: Run HID tests to verify they fail**

Run:

```powershell
powershell -ExecutionPolicy Bypass -File tools/run-node.ps1 --test host/test/hid-frame.test.js
```

Expected: FAIL because `host/src/hid-frame.js` does not exist.

- [ ] **Step 3: Implement HID frame encoder**

Create `host/src/hid-frame.js`:

```js
import { ANIMATION, SLOT_COUNT, STATE, STATE_RENDERING } from './states.js';

const FRAME_SIZE = 64;
const SLOT_SIZE = 8;
const SLOT_OFFSET = 8;

const STATE_CODE = Object.freeze({
  [STATE.IDLE]: 0,
  [STATE.RUNNING]: 1,
  [STATE.APPROVAL]: 2,
  [STATE.DONE]: 3,
  [STATE.ERROR]: 4,
});

const ANIMATION_CODE = Object.freeze({
  [ANIMATION.OFF]: 0,
  [ANIMATION.STEADY]: 1,
  [ANIMATION.BREATHE]: 2,
  [ANIMATION.PULSE]: 3,
  [ANIMATION.WARNING]: 4,
});

export function encodeDisplayFrame({ seq = 0, brightness = 255, flags = 0, slots = [] }) {
  const frame = new Uint8Array(FRAME_SIZE);

  frame[0] = 'T'.charCodeAt(0);
  frame[1] = 'L'.charCodeAt(0);
  frame[2] = 1;
  frame[3] = byte(seq);
  frame[4] = byte(brightness);
  frame[5] = byte(flags);
  frame[6] = 0;
  frame[7] = 0;

  for (let index = 0; index < SLOT_COUNT; index += 1) {
    encodeSlot(frame, index, slots[index]);
  }

  frame[63] = crc8(frame.subarray(0, 63));
  return frame;
}

function encodeSlot(frame, index, slot) {
  const offset = SLOT_OFFSET + index * SLOT_SIZE;
  const state = slot?.state ?? STATE.IDLE;
  const rendering = STATE_RENDERING[state] ?? STATE_RENDERING[STATE.IDLE];

  frame[offset] = STATE_CODE[state] ?? 0;
  frame[offset + 1] = ANIMATION_CODE[slot?.anim ?? rendering.animation] ?? ANIMATION_CODE[rendering.animation];
  frame[offset + 2] = byte(slot?.intensity ?? rendering.intensity);
  frame[offset + 3] = byte(slot?.age ?? 0);

  const hash = labelHash(slot?.sessionId ?? '');
  frame[offset + 4] = hash & 0xff;
  frame[offset + 5] = (hash >> 8) & 0xff;
  frame[offset + 6] = 0;
  frame[offset + 7] = 0;
}

function byte(value) {
  const number = Number.isFinite(value) ? Math.round(value) : 0;
  return Math.max(0, Math.min(255, number));
}

function labelHash(value) {
  let hash = 5381;
  for (const character of value) {
    hash = ((hash << 5) + hash + character.charCodeAt(0)) & 0xffff;
  }
  return hash;
}

function crc8(bytes) {
  let crc = 0x5a;
  for (const byteValue of bytes) {
    crc ^= byteValue;
    for (let bit = 0; bit < 8; bit += 1) {
      crc = (crc & 0x80) ? ((crc << 1) ^ 0x07) & 0xff : (crc << 1) & 0xff;
    }
  }
  return crc;
}
```

- [ ] **Step 4: Run HID tests to verify they pass**

Run:

```powershell
powershell -ExecutionPolicy Bypass -File tools/run-node.ps1 --test host/test/hid-frame.test.js
```

Expected: PASS for 4 tests.

- [ ] **Step 5: Run all host tests**

Run:

```powershell
powershell -ExecutionPolicy Bypass -File tools/run-node.ps1 --test host/test/*.test.js
```

Expected: PASS for all implemented tests.

- [ ] **Step 6: Commit HID encoder**

Run:

```bash
git add host/src/hid-frame.js host/test/hid-frame.test.js
git commit -m "feat: encode HID display frames"
```
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

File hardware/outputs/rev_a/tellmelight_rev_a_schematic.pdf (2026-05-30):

1 | 2 | 3 | 4 | 5 | 6
1 | 2 | 3 | 4 | 5 | 6

AB

C

D

AB

C

D Date: 2026-05-30

Size: A4 | Rev: A0
KiCad E.D.A. 10.0.3 | Id: 1/1

## Title: TellMeLight Rev A

File: tellmelight_rev_a.kicad_sch

Sheet: /

### TellMeLight

USB-C RP2040 + LP5024 six-zone AI session light

Block-level schematic baseline generated by tools/hardware/generate-rev-a-kicad.mjs

# SW1 BOOT D2 RGB_LED

D6 RGB_LED

D5 RGB_LED U3 W25Q32JVSS | U4

AP2112K-3.3

SWD1

# SWD_1x05 D1 RGB_LED

# D4 RGB_LED U2

LP5024

J1 USB_C_Receptacle_USB2.0 U1 RP2040 D3 RGB_LED

# SW2 RESET U5

TPD2EUSB30

Y1

12MHz

## TellMeLight Rev A KiCad schematic baseline

USB-C J1: VBUS enters protected 5V rail; CC1/CC2 use 5.1k Rd pull-downs. USB data: J1 D+/D- -> TPD2EUSB30 U5 -> 27R series resistors -> RP2040 U1 USB pins. Power: VBUS -> AP2112K-3.3 U4 -> 3V3 for RP2040, flash, and LP5024 logic. MCU: RP2040 U1 uses W25Q32JVSS U3 QSPI flash, 12 MHz Y1, SWD1, BOOT SW1, RESET SW2. LED driver: RP2040 I2C0 SDA/SCL -> LP5024 U2 with 4.7k pull-ups to 3V3. Light zones: LP5024 OUT0..OUT17 sink six common-anode RGB LEDs D1..D6 from VLED. Reserved: LP5024 OUT18..OUT23 are kept for Rev B brightness or status expansion. This file is the Rev A block-level schematic/net plan. Pin-by-pin signoff remains a review item. KiCad BOM placeholders below represent selected Rev A components; wiring still follows the net-plan notes above.

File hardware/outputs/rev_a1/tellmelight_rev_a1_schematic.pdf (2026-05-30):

1 | 2 | 3 | 4 | 5 | 6
1 | 2 | 3 | 4 | 5 | 6

AB

C

D

AB

C

D Date: 2026-05-30

KiCad E.D.A. 10.0.3

Size: A4 | Rev: A1 Id: 1/1

## Title: TellMeLight Rev A1

File: tellmelight_rev_a1.kicad_sch

Sheet: /

### TellMeLight

USB-C RP2040 + LP5024 six-zone AI session light

JLC-oriented block-level schematic generated by tools/hardware/generate-rev-a1-kicad.mjs U1 RP2040 | U2

LP5024RSMR

D3

S4-3528RGBTA-A

Y1

12MHz
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

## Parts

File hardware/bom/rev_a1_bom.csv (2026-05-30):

Designator | Qty | Kind | Value | Footprint | Preferred Part | JLC Candidate | Assembly Side | Notes | Status
U1 | 1 | MCU | RP2040 | Package_DFN_QFN:QFN-56-1EP_7x7mm_P0.4mm_EP3.2x3.2mm_ThermalVias | Raspberry Pi RP2040 | C2040 | Bottom | USB device controller; QFN-56 7x7 mm | review
U2 | 1 | LED_DRIVER | LP5024RSMR | Package_DFN_QFN:VQFN-32-1EP_4x4mm_P0.4mm_EP2.8x2.8mm_ThermalVias | TI LP5024RSMR | C427525 | Bottom | 24-channel I2C RGB LED driver; 18 channels used | review
U3 | 1 | FLASH | W25Q32JVSSIQ | Package_SO:SOIC-8_3.9x4.9mm_P1.27mm | Winbond W25Q32JVSSIQ | C82344 | Bottom | QSPI flash for RP2040 firmware | review
U4 | 1 | LDO | AP2112K-3.3TRG1 | Package_TO_SOT_SMD:SOT-23-5 | Diodes Inc AP2112K-3.3TRG1 | C51118 | Bottom | 3V3 regulator from USB VBUS | review
U5 | 1 | USB_ESD | TPD2EUSB30DRTR | Package_TO_SOT_SMD:SOT-23-6 | TI TPD2EUSB30DRTR | C94934 | Bottom | USB D+/D- ESD protection near J1 | review
J1 | 1 | USB_C | USB_C_Receptacle_USB2.0 | Connector_USB:USB_C_Receptacle_HRO_TYPE-C-31-M-12 | HRO TYPE-C-31-M-12 | C165948 | Bottom | USB-C power and full-speed data | review
TP_SWDIO,TP_SWCLK,TP_RUN,TP_3V3,TP_GND | 5 | DEBUG | Pogo test pads | TestPoint:TestPoint_Pad_D1.0mm | Generic 1.0 mm SMT test pad | JLC basic mechanical | Bottom | SWDIO, SWCLK, RUN, 3V3, GND without a through-hole header | review
SW1,SW2 | 2 | SWITCH | BOOT_RESET | Button_Switch_SMD:SW_SPST_EVQP2_ShortPushTravel_H2.1mm | Panasonic EVQP2-class | JLC matched switch | Bottom | BOOTSEL and reset service buttons on back | review
Y1 | 1 | CRYSTAL | 12MHz | Crystal:Crystal_SMD_TXC_7M-4Pin_3.2x2.5mm | 12 MHz 3.2x2.5 mm crystal | JLC matched crystal | Bottom | RP2040 clock source; validate load caps with selected crystal | review
D1-D6 | 6 | RGB_LED | S4-3528RGBTA-A | LED_SMD:LED_RGB_Wuerth-PLCC4_3.2x2.8mm_150141M173100 | OPSCO S4-3528RGBTA-A | C2827321 | Top | Common-anode RGB emitters under diffuser bars | review
R1,R2 | 2 | RESISTOR | 27R | Resistor_SMD:R_0603_1608Metric | 1% 0603 resistor | JLC basic 0603 | Bottom | USB D+/D- series resistors | review
R3,R4 | 2 | RESISTOR | 5.1k | Resistor_SMD:R_0603_1608Metric | 1% 0603 resistor | JLC basic 0603 | Bottom | USB-C CC pull-downs | review
R5,R6 | 2 | RESISTOR | 4.7k | Resistor_SMD:R_0603_1608Metric | 1% 0603 resistor | JLC basic 0603 | Bottom | I2C pull-ups to 3V3 | review
C1-C10 | 10 | CAPACITOR | 100nF | Capacitor_SMD:C_0603_1608Metric | X7R 0603 capacitor | JLC basic 0603 | Bottom | Local IC decoupling | review
C11,C12 | 2 | CAPACITOR | 10uF | Capacitor_SMD:C_0603_1608Metric | X5R/X7R 0603 or 0805 capacitor | JLC basic/common | Bottom | LDO input/output and LED rail bulk | review
C13,C14 | 2 | CAPACITOR | Crystal load | Capacitor_SMD:C_0603_1608Metric | Load capacitor matched to selected crystal | JLC matched capacitor | Bottom | RP2040 crystal load caps | review
TP1-TP8 | 8 | TESTPOINT | 1.0mm pad | TestPoint:TestPoint_Pad_D1.0mm | Generic 1.0 mm SMT test pad | JLC basic mechanical | Bottom | VBUS, 3V3, GND, I2C, USB, RUN bring-up points | review
H1-H4 | 4 | MECHANICAL | M2 mounting hole | MountingHole:MountingHole_2.2mm_M2 | Generic M2 clearance | Not assembled | Mechanical | Optional enclosure/diffuser fastening | review

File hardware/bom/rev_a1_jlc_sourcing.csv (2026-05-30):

Designator | Preferred Part | JLC Candidate | Library Status | Assembly Risk | Action Before Order
U1 | Raspberry Pi RP2040 | C2040 | JLC partdetail verified 2026-05-30 | QFN-56 exposed pad | Review RP2040 hardware design recommendations and thermal pad stencil
U2 | TI LP5024RSMR | C427525 | JLC partdetail verified 2026-05-30 | VQFN-32 exposed pad and fine pitch | Review LP5024 footprint, paste windowing, I2C address strap, and channel pinout
U3 | Winbond W25Q32JVSSIQ | C82344 | JLC partdetail verified 2026-05-30 | SOIC-8 low risk | Confirm RP2040 QSPI pin mapping before release
U4 | Diodes Inc AP2112K-3.3TRG1 | C51118 | JLC partdetail verified 2026-05-30 | SOT-23-5 low risk | Confirm input/output capacitor ESR and voltage rating
U5 | TI TPD2EUSB30DRTR | C94934 | JLC partdetail verified 2026-05-30 | Small USB ESD package | Place near USB-C connector and confirm pad numbering
J1 | HRO TYPE-C-31-M-12 | C165948 | JLC partdetail verified 2026-05-30 | Connector mechanical alignment and shell paste | Check USB-C footprint, shell grounding, and board-edge keepout
D1-D6 | OPSCO S4-3528RGBTA-A | C2827321 | JLC partdetail verified 2026-05-30 | RGB pinout must match selected footprint | Verify common-anode pin mapping against final datasheet before ordering
R/C passives | 0603 JLC basic/common families | JLC basic/common | Use BOM matching at order time | Low | Lock exact C-codes after price/stock review
Y1 | 12 MHz 3.2 x 2.5 mm crystal | JLC matched crystal | Use BOM matching at order time | Load cap value depends on crystal CL | Pick final crystal and capacitor values together
SW1,SW2 | SMD tactile service buttons | JLC matched switch | Use BOM matching at order time | Service controls on back only | Confirm height clears enclosure and diffuser stack

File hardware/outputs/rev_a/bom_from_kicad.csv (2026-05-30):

Refs | Value | Footprint | Qty | DNP
D1 | RGB_LED | LED_SMD:LED_RGB_PLCC-6 | 1
D2 | RGB_LED | LED_SMD:LED_RGB_PLCC-6 | 1
D3 | RGB_LED | LED_SMD:LED_RGB_PLCC-6 | 1
D4 | RGB_LED | LED_SMD:LED_RGB_PLCC-6 | 1
D5 | RGB_LED | LED_SMD:LED_RGB_PLCC-6 | 1
D6 | RGB_LED | LED_SMD:LED_RGB_PLCC-6 | 1
J1 | USB_C_Receptacle_USB2.0 | Connector_USB:USB_C_Receptacle_HRO_TYPE-C-31-M-12 | 1
SW1 | BOOT | Button_Switch_SMD:SW_SPST_EVQP2_ShortPushTravel_H2.1mm | 1
SW2 | RESET | Button_Switch_SMD:SW_SPST_EVQP2_ShortPushTravel_H2.1mm | 1
SWD1 | SWD_1x05 | Connector_PinHeader_1.27mm:PinHeader_1x05_P1.27mm_Vertical | 1
U1 | RP2040 | Package_DFN_QFN:QFN-56-1EP_7x7mm_P0.4mm_EP3.2x3.2mm_ThermalVias | 1
U2 | LP5024 | Package_DFN_QFN:VQFN-32-1EP_4x4mm_P0.4mm_EP2.8x2.8mm_ThermalVias | 1
U3 | W25Q32JVSS | Package_SO:SOIC-8_3.9x4.9mm_P1.27mm | 1
U4 | AP2112K-3.3 | Package_TO_SOT_SMD:SOT-23-5 | 1
U5 | TPD2EUSB30 | Package_TO_SOT_SMD:SOT-23-6 | 1
Y1 | 12MHz | Crystal:Crystal_SMD_TXC_7M-4Pin_3.2x2.5mm | 1

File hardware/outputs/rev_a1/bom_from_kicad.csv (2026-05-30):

Refs | Value | Footprint | Qty | DNP
D1 | S4-3528RGBTA-A | LED_SMD:LED_RGB_Wuerth-PLCC4_3.2x2.8mm_150141M173100 | 1
D2 | S4-3528RGBTA-A | LED_SMD:LED_RGB_Wuerth-PLCC4_3.2x2.8mm_150141M173100 | 1
D3 | S4-3528RGBTA-A | LED_SMD:LED_RGB_Wuerth-PLCC4_3.2x2.8mm_150141M173100 | 1
D4 | S4-3528RGBTA-A | LED_SMD:LED_RGB_Wuerth-PLCC4_3.2x2.8mm_150141M173100 | 1
D5 | S4-3528RGBTA-A | LED_SMD:LED_RGB_Wuerth-PLCC4_3.2x2.8mm_150141M173100 | 1
D6 | S4-3528RGBTA-A | LED_SMD:LED_RGB_Wuerth-PLCC4_3.2x2.8mm_150141M173100 | 1
J1 | USB_C_Receptacle_USB2.0 | Connector_USB:USB_C_Receptacle_HRO_TYPE-C-31-M-12 | 1
SW1 | BOOT | Button_Switch_SMD:SW_SPST_EVQP2_ShortPushTravel_H2.1mm | 1
SW2 | RESET | Button_Switch_SMD:SW_SPST_EVQP2_ShortPushTravel_H2.1mm | 1
TP9 | TP_SWDIO | TestPoint:TestPoint_Pad_D1.0mm | 1
TP10 | TP_SWCLK | TestPoint:TestPoint_Pad_D1.0mm | 1
TP11 | TP_RUN | TestPoint:TestPoint_Pad_D1.0mm | 1
TP12 | TP_3V3 | TestPoint:TestPoint_Pad_D1.0mm | 1
TP13 | TP_GND | TestPoint:TestPoint_Pad_D1.0mm | 1
U1 | RP2040 | Package_DFN_QFN:QFN-56-1EP_7x7mm_P0.4mm_EP3.2x3.2mm_ThermalVias | 1
U2 | LP5024RSMR | Package_DFN_QFN:VQFN-32-1EP_4x4mm_P0.4mm_EP2.8x2.8mm_ThermalVias | 1
U3 | W25Q32JVSSIQ | Package_SO:SOIC-8_3.9x4.9mm_P1.27mm | 1
U4 | AP2112K-3.3TRG1 | Package_TO_SOT_SMD:SOT-23-5 | 1
U5 | TPD2EUSB30DRTR | Package_TO_SOT_SMD:SOT-23-6 | 1
Y1 | 12MHz | Crystal:Crystal_SMD_TXC_7M-4Pin_3.2x2.5mm | 1

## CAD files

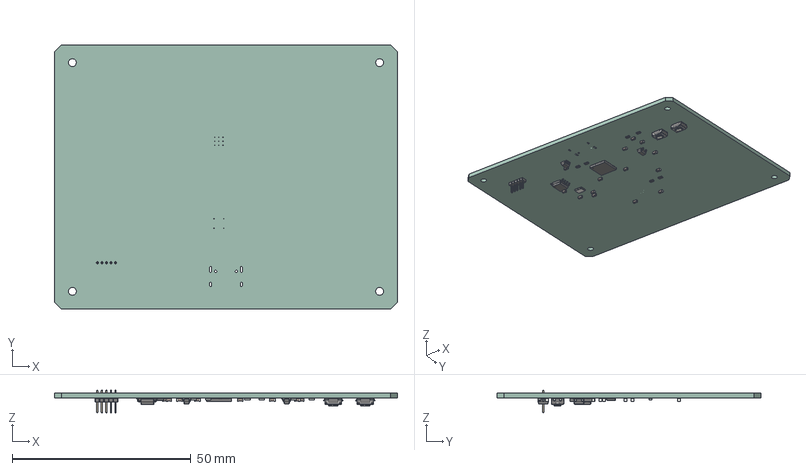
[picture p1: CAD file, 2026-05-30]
hardware/outputs/rev_a/tellmelight_rev_a.step
96.0 x 74.0 x 6.30 mm
SW_SPST_EVQP2_ShortPushTravel_H2.1mm x 2
PinHeader_1x05_P127mm_Vertical
C_0603_1608Metric x 14
Crystal_SMD_TXC_7M-4Pin_3.2x2.5mm
R_0603_1608Metric x 6
SOIC-8_3.9x4.9mm_P1.27mm
SOT-23-5
SOT-23-6
QFN-56-1EP_7x7mm_P0.4mm_EP3.2x3.2mm
tellmelight_rev_a_PCB

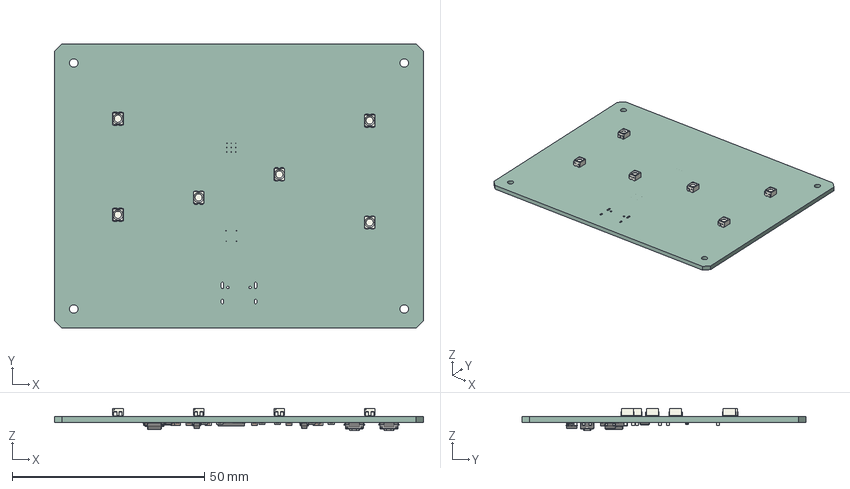
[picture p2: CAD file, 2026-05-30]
hardware/outputs/rev_a1/tellmelight_rev_a1.step
96.0 x 74.0 x 5.83 mm
LED_RGB_Wuerth-PLCC4_3.2x2.8mm_150141M173100 x 6
R_0603_1608Metric x 6
SOIC-8_3.9x4.9mm_P1.27mm
C_0603_1608Metric x 14
SW_SPST_EVQP2_ShortPushTravel_H2.1mm x 2
SOT-23-5
QFN-56-1EP_7x7mm_P0.4mm_EP3.2x3.2mm
SOT-23-6
Crystal_SMD_TXC_7M-4Pin_3.2x2.5mm
tellmelight_rev_a1_PCB

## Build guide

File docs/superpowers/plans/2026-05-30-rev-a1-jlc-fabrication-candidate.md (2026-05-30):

# Rev A1 JLC Fabrication Candidate Implementation Plan

> **For agentic workers:** REQUIRED SUB-SKILL: Use superpowers:subagent-driven-development (recommended) or superpowers:executing-plans to implement this plan task-by-task. Steps use checkbox (`- [ ]`) syntax for tracking.

**Goal:** Generate and verify a Rev A1 KiCad/BOM/manufacturing baseline aimed at JLC/JLCPCB SMT assembly.

**Architecture:** Keep Rev A as the preserved exploratory baseline and create a separate Rev A1 project tree. A Node generator writes deterministic docs, BOM, sourcing, schematic symbol assets, and power tables. A KiCad Python generator creates the 4-layer PCB floorplan using stock footprints, JLC-oriented component choices, and front/back assembly separation.

**Tech Stack:** KiCad 10.0.3 CLI, KiCad `pcbnew` Python API, JavaScript ES modules, Node `node:test`, PowerShell runner.

---

## File Structure

- Create `hardware/kicad/tellmelight_rev_a1/`: Rev A1 KiCad project, schematic, board, symbol table, and local README.
- Create `hardware/bom/rev_a1_bom.csv`: design BOM with selected footprints and JLC candidate part codes.
- Create `hardware/bom/rev_a1_jlc_sourcing.csv`: order-prep sourcing table with C-codes and risk status.
- Create `hardware/simulation/rev_a1_power_budget.csv`: machine-readable Rev A1 current budget.
- Create `hardware/simulation/rev_a1_power_budget.md`: readable Rev A1 power notes.
- Create `hardware/outputs/rev_a1/`: ERC, DRC, Gerbers, drill, position, STEP, PDF/SVG, PNG, and summary output.
- Create `hardware/notes/rev-a1-jlc-readiness.md`: human review checklist for JLC assembly readiness.
- Create `tools/hardware/generate-rev-a1-kicad.mjs`: deterministic Rev A1 project/document generator.
- Create `tools/hardware/generate_rev_a1_board.py`: KiCad `pcbnew` board generator.
- Create `host/test/hardware-rev-a1-assets.test.js`: tests for Rev A1 decisions and generated artifacts.
- Modify `README.md`: add Rev A1 generation and verification commands.
- Modify `docs/superpowers/brainstorm/2026-05-29-tellmelight-progress.md`: record generated Rev A1 checkpoint after verification.

## Task 1: Rev A1 Tests

- [ ] **Step 1: Add failing tests**

Create `host/test/hardware-rev-a1-assets.test.js` with these assertions:

```js
import assert from 'node:assert/strict';
import { readFile } from 'node:fs/promises';
import test from 'node:test';

async function readText(path) {
  return readFile(path, 'utf8');
}

test('rev A1 spec records JLC-oriented manufacturing decisions', async () => {
  const spec = await readText('docs/superpowers/specs/2026-05-30-rev-a1-jlc-fabrication-candidate-design.md');

  assert.match(spec, /4-layer PCB/);
  assert.match(spec, /double-sided SMT/);
  assert.match(spec, /pogo\/test pads/);
  assert.match(spec, /C427525/);
  assert.match(spec, /C2827321/);
});
```

Add more tests in the same file for BOM, sourcing table, board, readiness note, and power budget:

```js
test('rev A1 generated files contain the required JLC candidate components', async () => {
  const bom = await readText('hardware/bom/rev_a1_bom.csv');
  const sourcing = await readText('hardware/bom/rev_a1_jlc_sourcing.csv');

  for (const token of ['RP2040', 'LP5024RSMR', 'W25Q32JVSSIQ', 'AP2112K-3.3TRG1', 'TPD2EUSB30DRTR', 'TYPE-C-31-M-12', 'S4-3528RGBTA-A']) {
    assert.match(bom, new RegExp(token.replaceAll('.', '\\.')));
  }

  for (const code of ['C2040', 'C427525', 'C82344', 'C51118', 'C94934', 'C165948', 'C2827321']) {
    assert.match(sourcing, new RegExp(code));
  }
});
```

```js
test('rev A1 KiCad PCB reflects 4-layer JLC productization direction', async () => {
  const pcb = await readText('hardware/kicad/tellmelight_rev_a1/tellmelight_rev_a1.kicad_pcb');

  for (const ref of ['U1', 'U2', 'U3', 'U4', 'U5', 'J1', 'D1', 'D2', 'D3', 'D4', 'D5', 'D6', 'TP_SWDIO', 'TP_SWCLK']) {
    assert.match(pcb, new RegExp(`\\b${ref}\\b`));
  }

  assert.match(pcb, /In1\.Cu/);
  assert.match(pcb, /In2\.Cu/);
  assert.match(pcb, /LED_RGB_Wuerth-PLCC4_3\.2x2\.8mm/);
  assert.doesNotMatch(pcb, /PinHeader_1x05/);
});
```

```js
test('rev A1 readiness and power notes capture no-hand-solder review gates', async () => {
  const readiness = await readText('hardware/notes/rev-a1-jlc-readiness.md');
  const power = await readText('hardware/simulation/rev_a1_power_budget.md');

  assert.match(readiness, /No assumed user hand-soldering/);
  assert.match(readiness, /JLC DFM review/);
  assert.match(readiness, /double-sided SMT/);
  assert.match(power, /Typical visible load/);
  assert.match(power, /USB current target/);
});
```

- [ ] **Step 2: Run test to verify failure**

Run:

```powershell
powershell -ExecutionPolicy Bypass -File tools/run-node.ps1 --test host/test/hardware-rev-a1-assets.test.js
```

Expected: FAIL because the Rev A1 generated files do not exist yet.

## Task 2: Rev A1 Document Generator

- [ ] **Step 1: Create `tools/hardware/generate-rev-a1-kicad.mjs`**

Copy the useful deterministic helpers from `tools/hardware/generate-rev-a-kicad.mjs`, then change the constants to Rev A1 paths:

```js
const projectDir = join(repoRoot, 'hardware', 'kicad', 'tellmelight_rev_a1');
const outputsDir = join(repoRoot, 'hardware', 'outputs', 'rev_a1');
const projectPath = join(projectDir, 'tellmelight_rev_a1.kicad_pro');
const schematicPath = join(projectDir, 'tellmelight_rev_a1.kicad_sch');
const boardPath = join(projectDir, 'tellmelight_rev_a1.kicad_pcb');
```

The generator must write:

- `tellmelight_rev_a1.kicad_pro`
- `tellmelight_rev_a1.kicad_sch`
- `tellmelight_rev_a1.kicad_sym`
- `sym-lib-table`
- `README.md`
- `hardware/bom/rev_a1_bom.csv`
- `hardware/bom/rev_a1_jlc_sourcing.csv`
- `hardware/simulation/rev_a1_power_budget.csv`
- `hardware/simulation/rev_a1_power_budget.md`
- `hardware/notes/rev-a1-jlc-readiness.md`

- [ ] **Step 2: Add Rev A1 BOM rows**

The BOM header must be:

```csv
Designator,Qty,Kind,Value,Footprint,Preferred Part,JLC Candidate,Assembly Side,Notes,Status
```

Required rows:

```csv
U1,1,MCU,RP2040,Package_DFN_QFN:QFN-56-1EP_7x7mm_P0.4mm_EP3.2x3.2mm_ThermalVias,Raspberry Pi RP2040,C2040,Bottom,USB device controller; QFN-56 7x7 mm,review
U2,1,LED_DRIVER,LP5024RSMR,Package_DFN_QFN:VQFN-32-1EP_4x4mm_P0.4mm_EP2.8x2.8mm_ThermalVias,TI LP5024RSMR,C427525,Bottom,24-channel I2C RGB LED driver; 18 channels used,review
D1-D6,6,RGB_LED,S4-3528RGBTA-A,LED_SMD:LED_RGB_Wuerth-PLCC4_3.2x2.8mm_150141M173100,OPSCO S4-3528RGBTA-A,C2827321,Top,Common-anode RGB emitters under diffuser bars,review
```

- [ ] **Step 3: Add sourcing table rows**

The sourcing table header must be:

```csv
Designator,Preferred Part,JLC Candidate,Library Status,Assembly Risk,Action Before Order
```

The main active/mechanical rows must include `C2040`, `C427525`, `C82344`, `C51118`, `C94934`, `C165948`, and `C2827321`.

- [ ] **Step 4: Add readiness note**

`hardware/notes/rev-a1-jlc-readiness.md` must include these exact review gates:

```markdown
- No assumed user hand-soldering.
- JLC DFM review before ordering.
- Double-sided SMT assembly pricing and capability check.
- LP5024 VQFN exposed-pad paste and thermal-pad review.
- RGB LED pinout verification against the final JLC selected part.
- USB-C connector footprint and shell grounding review.
```

## Task 3: Rev A1 Board Generator

- [ ] **Step 1: Create `tools/hardware/generate_rev_a1_board.py`**

Start from `tools/hardware/generate_rev_a_board.py`, then change:

- Board title to `TellMeLight Rev A1`.
- Revision to `A1`.
- LED footprint to `LED_RGB_Wuerth-PLCC4_3.2x2.8mm_150141M173100`.
- SWD header footprint to individual `TestPoint:TestPoint_Pad_D1.0mm` pads named `TP_SWDIO`, `TP_SWCLK`, `TP_RUN`, `TP_3V3`, and `TP_GND`.

- [ ] **Step 2: Configure 4-layer stack**

Add internal copper layers before saving the board. The board file must include these layer names:

```text
In1.Cu
In2.Cu
```

If the `pcbnew` API call is not stable for layer-count setup, post-process the generated board text to insert the 4-layer `(layers ...)` block while preserving KiCad readability.

- [ ] **Step 3: Keep front/back product placement**

Placement requirements:

- D1-D6 on the front.
- U1, U2, U3, U4, U5, J1, passives, service buttons, and test pads on the back.
- Mounting holes remain mechanical and unassembled.

- [ ] **Step 4: Add JLC-oriented board markings**

Add front/back text:

```text
TellMeLight Rev A1
JLC SMT review
No hand solder
```

## Task 4: Generate Rev A1 Assets

- [ ] **Step 1: Run generator**

Run:

```powershell
powershell -ExecutionPolicy Bypass -File tools/run-node.ps1 tools/hardware/generate-rev-a1-kicad.mjs
```

Expected: `Generated Rev A1 KiCad hardware baseline` appears.

- [ ] **Step 2: Run Rev A1 tests**

Run:

```powershell
powershell -ExecutionPolicy Bypass -File tools/run-node.ps1 --test host/test/hardware-rev-a1-assets.test.js
```

Expected: PASS.

## Task 5: KiCad CLI Verification And Exports

- [ ] **Step 1: Run schematic checks**

```powershell
& E:\kicad\bin\kicad-cli.exe sch erc --format json -o hardware/outputs/rev_a1/erc.json hardware/kicad/tellmelight_rev_a1/tellmelight_rev_a1.kicad_sch
& E:\kicad\bin\kicad-cli.exe sch export bom -o hardware/outputs/rev_a1/bom_from_kicad.csv hardware/kicad/tellmelight_rev_a1/tellmelight_rev_a1.kicad_sch
& E:\kicad\bin\kicad-cli.exe sch export netlist -o hardware/outputs/rev_a1/netlist.xml hardware/kicad/tellmelight_rev_a1/tellmelight_rev_a1.kicad_sch
```

- [ ] **Step 2: Run PCB checks and exports**

```powershell
& E:\kicad\bin\kicad-cli.exe pcb drc --format json -o hardware/outputs/rev_a1/drc.json hardware/kicad/tellmelight_rev_a1/tellmelight_rev_a1.kicad_pcb
& E:\kicad\bin\kicad-cli.exe pcb export gerbers -o hardware/outputs/rev_a1/gerbers hardware/kicad/tellmelight_rev_a1/tellmelight_rev_a1.kicad_pcb
& E:\kicad\bin\kicad-cli.exe pcb export drill -o hardware/outputs/rev_a1/drill hardware/kicad/tellmelight_rev_a1/tellmelight_rev_a1.kicad_pcb
& E:\kicad\bin\kicad-cli.exe pcb export pos -o hardware/outputs/rev_a1/pos hardware/kicad/tellmelight_rev_a1/tellmelight_rev_a1.kicad_pcb
& E:\kicad\bin\kicad-cli.exe pcb export step -o hardware/outputs/rev_a1/tellmelight_rev_a1.step hardware/kicad/tellmelight_rev_a1/tellmelight_rev_a1.kicad_pcb
& E:\kicad\bin\kicad-cli.exe pcb render -o hardware/outputs/rev_a1/tellmelight_rev_a1_top.png --side top --width 1600 --height 1200 hardware/kicad/tellmelight_rev_a1/tellmelight_rev_a1.kicad_pcb
& E:\kicad\bin\kicad-cli.exe pcb render -o hardware/outputs/rev_a1/tellmelight_rev_a1_bottom.png --side bottom --width 1600 --height 1200 hardware/kicad/tellmelight_rev_a1/tellmelight_rev_a1.kicad_pcb
```

- [ ] **Step 3: Write verification summary**

Create `hardware/outputs/rev_a1/verification-summary.md` recording:

- Commands run.
- ERC result.
- DRC result.
- STEP/render warnings.
- Remaining order blockers.

## Task 6: Repository Docs And Final Verification

- [ ] **Step 1: Update `README.md`**

Add the Rev A1 generator command and output paths near the Rev A hardware commands.

- [ ] **Step 2: Update progress log**

Append a Rev A1 generated-assets checkpoint to `docs/superpowers/brainstorm/2026-05-29-tellmelight-progress.md`.

- [ ] **Step 3: Run all repository tests**

```powershell
powershell -ExecutionPolicy Bypass -File tools/run-node.ps1 --test host/test/*.test.js
```

Expected: all tests pass.

- [ ] **Step 4: Run whitespace check**

```powershell
git diff --check
```

Expected: no output.

- [ ] **Step 5: Commit and push**

```powershell
git add README.md docs/superpowers/brainstorm/2026-05-29-tellmelight-progress.md host/test/hardware-rev-a1-assets.test.js tools/hardware/generate-rev-a1-kicad.mjs tools/hardware/generate_rev_a1_board.py hardware/bom/rev_a1_bom.csv hardware/bom/rev_a1_jlc_sourcing.csv hardware/kicad/tellmelight_rev_a1 hardware/notes/rev-a1-jlc-readiness.md hardware/simulation/rev_a1_power_budget.csv hardware/simulation/rev_a1_power_budget.md hardware/outputs/rev_a1
git commit -m "feat: add rev a1 jlc hardware baseline"
git push origin feature/local-simulation-foundation
```

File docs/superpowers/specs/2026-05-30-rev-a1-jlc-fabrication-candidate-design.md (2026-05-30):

# Rev A1 JLC Fabrication Candidate Design

Date: 2026-05-30

## Goal

Turn the Rev A KiCad baseline into a JLC-oriented fabrication candidate for TellMeLight: still local-only and not order-ready, but now shaped around high integration, no user hand-soldering, and a product-like visual finish.

Rev A1 keeps the six-session FIFO behavior and four-bar visual language from Rev A. The change is manufacturing discipline: component sourcing, assembly side strategy, stackup, test access, and design notes should now make sense for a JLCPCB/JLC PCBA workflow.

## User Constraints

- The user likely wants to fabricate through JLC/JLCPCB.
- The user does not currently have soldering tools and prefers not to hand-solder.
- The hardware should look polished and technical, not like a dev board.
- Cost is not yet known well enough to drive every decision, so Rev A1 should make conservative engineering defaults and clearly mark cost-sensitive gates.
- Work should continue on local artifacts first: KiCad, BOM, exports, manufacturing notes, and verification. No real PCB order is placed in this milestone.

## Manufacturing Approach

Recommended approach: use a high-integration JLC SMT assembly path.

- Use a 4-layer PCB by default.
  - L1: front optical LEDs, local routing, display guide artwork.
  - L2: continuous ground plane.
  - L3: 3V3 and VLED power distribution.
  - L4: back-side MCU, USB, LED driver, flash, regulator, passives, and debug pads.
- Use double-sided SMT placement:
  - Front side holds only the six RGB emitters and product-facing marks.
  - Back side holds logic, power, USB, test pads, and service controls.
- Avoid through-hole hand assembly.
- Replace the 1.27 mm SWD header with pogo/test pads for product-like appearance, while keeping the signal set for bring-up.
- Prefer black solder mask and ENIG for the product-looking prototype if cost is acceptable at order time. Green solder mask/HASL is the fallback for a cheaper engineering sample.
- Treat JLC official DFM and parts-library matching as required checks before ordering.

Official references checked for Rev A1 assumptions:

- JLCPCB capabilities: `https://jlcpcb.com/capabilities/Capabilities`
- JLCPCB PCB assembly service: `https://jlcpcb.com/pcb-assembly`
- JLCPCB parts library: `https://jlcpcb.com/parts`
- Raspberry Pi RP2040 datasheet: `https://datasheets.raspberrypi.com/rp2040/rp2040-datasheet.pdf`
- TI LP5024 datasheet: `https://www.ti.com/lit/ds/symlink/lp5024.pdf`

## Architecture Decision

Use the existing RP2040 + LP5024 architecture.

Alternatives considered:

1. RP2040 + LP5024 + six discrete common-anode RGB LEDs.
   - Best fit for a product-like device.
   - Hardware PWM/current control is clean and expandable.
   - The LP5024 is available in the JLC parts ecosystem as `C427525` for `LP5024RSMR`.
   - Requires careful QFN/VQFN layout and assembly review.
2. RP2040 + six addressable RGB LEDs.
   - Lowest part count and simple routing.
   - Less product-like for a polished hardware design, tighter firmware timing behavior, and less graceful current control.
3. RP2040 module or dev-board-style carrier.
   - Fastest bring-up.
   - Conflicts with the integrated aesthetic and adds board-to-board/package constraints.

Rev A1 selects option 1.

## Component Direction

Rev A1 should keep these main components:

- U1: Raspberry Pi `RP2040`, JLC candidate `C2040`.
- U2: TI `LP5024RSMR`, JLC candidate `C427525`.
- U3: Winbond `W25Q32JVSSIQ` QSPI flash, JLC candidate `C82344`.
- U4: Diodes Inc `AP2112K-3.3TRG1` 3V3 LDO, JLC candidate `C51118`.
- U5: TI `TPD2EUSB30DRTR` USB ESD protector, JLC candidate `C94934`.
- J1: HRO `TYPE-C-31-M-12` USB-C USB2 receptacle, JLC candidate `C165948`.
- D1-D6: common-anode 4-pin 3528 RGB LED, with `S4-3528RGBTA-A` / JLC `C2827321` as the first sourcing candidate.

Rev A1 intentionally changes the LED footprint direction from generic `LED_RGB_PLCC-6` to a 4-pin PLCC/3528 common-anode style because it better matches JLC-assembly-friendly commodity RGB emitters.

Passives should use JLC basic/common 0603 parts where possible:

- 27 ohm USB series resistors.
- 5.1 kohm USB-C CC pull-down resistors.
- 4.7 kohm I2C pull-ups.
- 100 nF X7R decoupling capacitors.
- 10 uF input/output/bulk capacitors sized for USB VBUS and 3V3 rails.
- Crystal load capacitors selected after the exact 12 MHz crystal is chosen.

## Electrical Requirements

- USB-C is a USB2 device connection for power and data.
- CC1 and CC2 each get a 5.1 kohm pull-down to ground.
- USB D+ and D- route through ESD protection and 27 ohm series resistors near the RP2040.
- RP2040 uses external QSPI flash and a 12 MHz crystal.
- LP5024 uses I2C from the RP2040 with 4.7 kohm pull-ups to 3V3.
- LP5024 OUT0..OUT17 drive six RGB zones; OUT18..OUT23 remain reserved.
- LEDs are common-anode and powered from VLED, with the LP5024 sinking each color channel.
- VLED is sourced from USB VBUS for Rev A1; firmware brightness limits keep USB current reasonable.
- 3V3 powers RP2040, flash, LED driver logic, ESD logic if needed, pull-ups, and debug pads.

## Mechanical And Visual Requirements

- Keep the approved four-bar display core:
  - Left long bar: two zones; shorter than the right long bar.
  - Left middle bar: one short zone; lower.
  - Right middle bar: one short zone; slightly higher and upright.
  - Right long bar: two zones; tallest visual bar.
- Keep the irregular rounded trapezoid direction:
  - Left long, left middle, and right long bars have the short edge facing right.
  - Right middle bar has the short edge facing left.
- Rev A1 PCB should keep front-side marks that help align a future diffuser, but it should not pretend to solve the enclosure.
- Add at least one manufacturing note that the diffuser, light isolation walls, and outer enclosure are Rev B mechanical work unless a user decision pulls them earlier.

## Deliverables

Rev A1 should produce:

- A Rev A1 KiCad project in `hardware/kicad/tellmelight_rev_a1/`.
- A Rev A1 BOM in `hardware/bom/rev_a1_bom.csv`.
- A JLC sourcing table in `hardware/bom/rev_a1_jlc_sourcing.csv`.
- A Rev A1 power budget in `hardware/simulation/`.
- KiCad CLI ERC, DRC, Gerber, drill, position, STEP, PDF/SVG, and PNG render outputs under `hardware/outputs/rev_a1/`.
- A manufacturing readiness note at `hardware/notes/rev-a1-jlc-readiness.md`.
- Repository tests that verify the Rev A1 files, sourcing decisions, and output paths exist.

## Verification Gate

Rev A1 is acceptable when:

- Repository tests pass.
- KiCad ERC completes with no violations.
- KiCad DRC completes with no violations or only explicitly documented non-order-blocking warnings.
- The BOM and sourcing table include JLC candidate codes or review status for every major component.
- The PCB keeps the approved visual geometry while moving the design toward 4-layer, no-hand-solder assembly.
- A verification summary records commands run, KiCad warnings, sourcing risks, and remaining human review gates.

## Non-Goals

- Do not place a real JLC order in Rev A1.
- Do not claim the board is fabrication-ready without a human electrical, footprint, and DFM review.
- Do not design the final enclosure or optical diffuser in this milestone.
- Do not switch to addressable LEDs unless the LP5024 sourcing or DFM check becomes a blocker.

## Decision Gates For The User

These are the next meaningful choices once Rev A1 artifacts exist:

- Whether to pay for 4-layer, double-sided SMT, black solder mask, and ENIG for the first board.
- Whether to keep the LP5024 route after JLC BOM matching, or switch to addressable LEDs for a cheaper EVT.
- Whether the Rev A1 board should expose visible buttons, hidden back buttons, or only pogo/test-pad service controls.
- Whether enclosure/diffuser CAD starts before or after the first electronic board order.

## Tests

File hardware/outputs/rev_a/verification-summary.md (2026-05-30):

# Rev A KiCad Verification Summary

Date: 2026-05-30

KiCad used: `E:\kicad\bin\kicad-cli.exe` version `10.0.3`.

## Source Files

- Project: `hardware/kicad/tellmelight_rev_a/tellmelight_rev_a.kicad_pro`
- Schematic: `hardware/kicad/tellmelight_rev_a/tellmelight_rev_a.kicad_sch`
- PCB: `hardware/kicad/tellmelight_rev_a/tellmelight_rev_a.kicad_pcb`
- Manual BOM: `hardware/bom/rev_a_bom.csv`
- Power budget: `hardware/simulation/rev_a_power_budget.md`

## Check Results

- Schematic ERC: 0 violations.
- PCB DRC: 0 violations, 0 unconnected items.
- Repository hardware asset tests: 4 pass, 0 fail.

## Export Results

- KiCad schematic BOM: `hardware/outputs/rev_a/bom_from_kicad.csv` with 16 component rows.
- Netlist: `hardware/outputs/rev_a/netlist.xml`.
- Gerbers: 25 files in `hardware/outputs/rev_a/gerbers`.
- Drill outputs: 3 files in `hardware/outputs/rev_a/drill`.
- Position file: `hardware/outputs/rev_a/pos/tellmelight_rev_a_pos.csv`.
- STEP: `hardware/outputs/rev_a/tellmelight_rev_a.step`.
- Schematic PDF/SVG: `hardware/outputs/rev_a/tellmelight_rev_a_schematic.pdf`, `hardware/outputs/rev_a/schematic_svg/tellmelight_rev_a.svg`.
- PCB PDF/SVG: `hardware/outputs/rev_a/tellmelight_rev_a_pcb.pdf`, `hardware/outputs/rev_a/tellmelight_rev_a_pcb_top.svg`.
- PCB renders: `hardware/outputs/rev_a/tellmelight_rev_a_top.png`, `hardware/outputs/rev_a/tellmelight_rev_a_bottom.png`.

## Known Export Notes

- STEP export succeeded, but KiCad reported missing stock 3D models for the RGB LED footprint, the LP5024-class VQFN footprint, and the selected USB-C footprint. The STEP file was still created.
- The schematic is a block-level net plan plus BOM placeholder symbols. It is useful for architecture review and BOM export, but it is not pin-by-pin fabrication signoff.
- The PCB is a footprint placement and mechanical/display baseline. Final routing, USB differential layout review, exact RGB LED selection, enclosure CAD, and PCB-vendor DFM remain open before fabrication.

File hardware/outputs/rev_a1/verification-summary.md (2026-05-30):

# Rev A1 Verification Summary

Date: 2026-05-30

## Generated Artifacts

- KiCad project: `hardware/kicad/tellmelight_rev_a1/`
- Manual BOM: `hardware/bom/rev_a1_bom.csv`
- JLC sourcing table: `hardware/bom/rev_a1_jlc_sourcing.csv`
- JLC readiness note: `hardware/notes/rev-a1-jlc-readiness.md`
- Power budget: `hardware/simulation/rev_a1_power_budget.md`
- Outputs: `hardware/outputs/rev_a1/`

## Commands Run

```powershell
powershell -ExecutionPolicy Bypass -File tools/run-node.ps1 tools/hardware/generate-rev-a1-kicad.mjs
powershell -ExecutionPolicy Bypass -File tools/run-node.ps1 --test host/test/hardware-rev-a1-assets.test.js
& E:\kicad\bin\kicad-cli.exe sch erc --format json -o hardware/outputs/rev_a1/erc.json hardware/kicad/tellmelight_rev_a1/tellmelight_rev_a1.kicad_sch
& E:\kicad\bin\kicad-cli.exe sch export bom -o hardware/outputs/rev_a1/bom_from_kicad.csv hardware/kicad/tellmelight_rev_a1/tellmelight_rev_a1.kicad_sch
& E:\kicad\bin\kicad-cli.exe sch export netlist -o hardware/outputs/rev_a1/netlist.xml hardware/kicad/tellmelight_rev_a1/tellmelight_rev_a1.kicad_sch
& E:\kicad\bin\kicad-cli.exe pcb drc --format json -o hardware/outputs/rev_a1/drc.json hardware/kicad/tellmelight_rev_a1/tellmelight_rev_a1.kicad_pcb
& E:\kicad\bin\kicad-cli.exe pcb export gerbers -o hardware/outputs/rev_a1/gerbers hardware/kicad/tellmelight_rev_a1/tellmelight_rev_a1.kicad_pcb
& E:\kicad\bin\kicad-cli.exe pcb export drill -o hardware/outputs/rev_a1/drill hardware/kicad/tellmelight_rev_a1/tellmelight_rev_a1.kicad_pcb
& E:\kicad\bin\kicad-cli.exe pcb export pos -o hardware/outputs/rev_a1/pos hardware/kicad/tellmelight_rev_a1/tellmelight_rev_a1.kicad_pcb
& E:\kicad\bin\kicad-cli.exe pcb export step -o hardware/outputs/rev_a1/tellmelight_rev_a1.step hardware/kicad/tellmelight_rev_a1/tellmelight_rev_a1.kicad_pcb
& E:\kicad\bin\kicad-cli.exe pcb export pdf -o hardware/outputs/rev_a1/tellmelight_rev_a1_pcb.pdf --layers F.Cu,In1.Cu,In2.Cu,B.Cu,F.Silkscreen,B.Silkscreen,Edge.Cuts --mode-multipage --scale 0 hardware/kicad/tellmelight_rev_a1/tellmelight_rev_a1.kicad_pcb
& E:\kicad\bin\kicad-cli.exe pcb export svg -o hardware/outputs/rev_a1/tellmelight_rev_a1_pcb_top.svg --layers F.Cu,F.Silkscreen,Edge.Cuts --mode-single --fit-page-to-board hardware/kicad/tellmelight_rev_a1/tellmelight_rev_a1.kicad_pcb
& E:\kicad\bin\kicad-cli.exe pcb export svg -o hardware/outputs/rev_a1/tellmelight_rev_a1_pcb_bottom.svg --layers B.Cu,B.Silkscreen,Edge.Cuts --mode-single --fit-page-to-board --mirror hardware/kicad/tellmelight_rev_a1/tellmelight_rev_a1.kicad_pcb
& E:\kicad\bin\kicad-cli.exe pcb render -o hardware/outputs/rev_a1/tellmelight_rev_a1_top.png --side top --width 1600 --height 1200 hardware/kicad/tellmelight_rev_a1/tellmelight_rev_a1.kicad_pcb
& E:\kicad\bin\kicad-cli.exe pcb render -o hardware/outputs/rev_a1/tellmelight_rev_a1_bottom.png --side bottom --width 1600 --height 1200 hardware/kicad/tellmelight_rev_a1/tellmelight_rev_a1.kicad_pcb
& E:\kicad\bin\kicad-cli.exe sch export pdf -o hardware/outputs/rev_a1/tellmelight_rev_a1_schematic.pdf hardware/kicad/tellmelight_rev_a1/tellmelight_rev_a1.kicad_sch
& E:\kicad\bin\kicad-cli.exe sch export svg -o hardware/outputs/rev_a1/schematic_svg hardware/kicad/tellmelight_rev_a1/tellmelight_rev_a1.kicad_sch
```

## Results

- Rev A1 asset tests: 4 passed, 0 failed.
- KiCad ERC: 0 violations.
- KiCad DRC: 0 violations and 0 unconnected items.
- Gerbers, drill, position, PDF, SVG, top render, bottom render, schematic PDF, and schematic SVG exported successfully.
- STEP export succeeded.

## Warnings

- STEP export reported missing stock 3D models for:
  - `U2` VQFN-32 LP5024 footprint.
  - `J1` HRO USB-C footprint.
- This is not a PCB fabrication blocker, but it is a mechanical review item before enclosure work.

## Remaining Order Blockers

- The schematic is still a block-level net plan with review symbols, not a pin-by-pin fabrication schematic.
- RGB LED pinout must be verified against the final JLC selected part before ordering.
- USB-C footprint, shell grounding, and connector mechanical fit need review.
- LP5024 exposed-pad stencil and paste-windowing need review.
- JLC BOM/CPL upload must be checked in the order UI before spending money.

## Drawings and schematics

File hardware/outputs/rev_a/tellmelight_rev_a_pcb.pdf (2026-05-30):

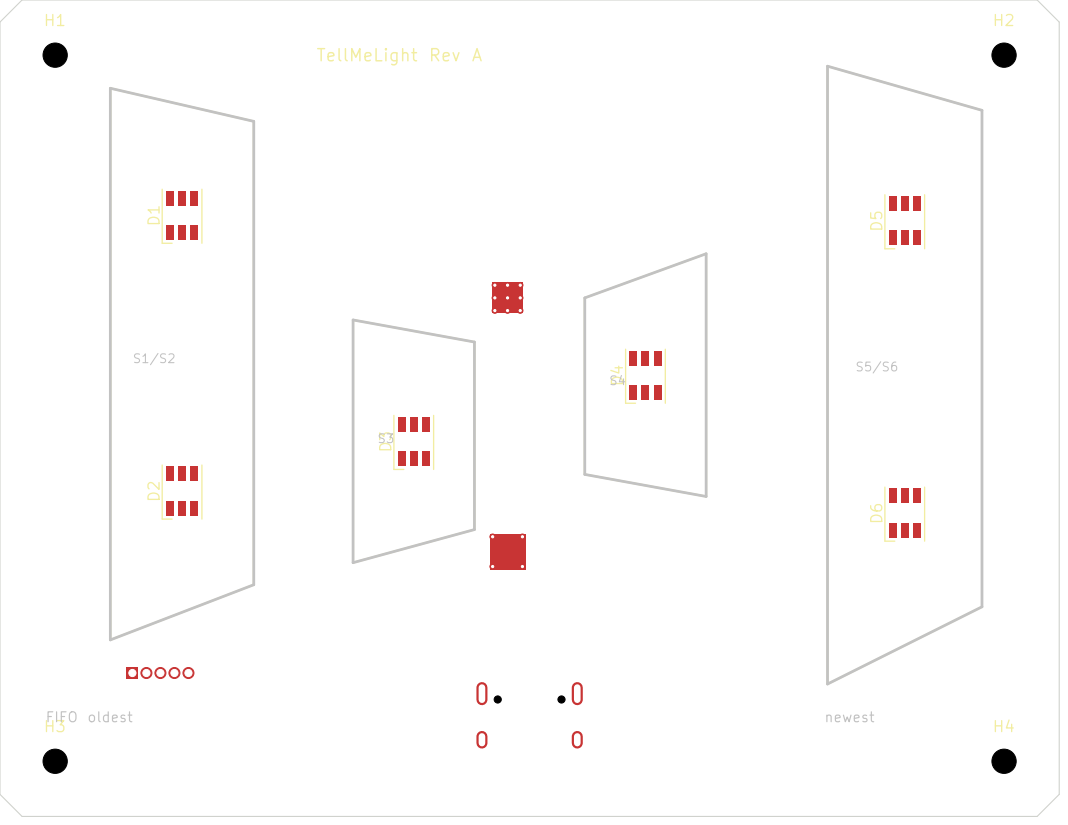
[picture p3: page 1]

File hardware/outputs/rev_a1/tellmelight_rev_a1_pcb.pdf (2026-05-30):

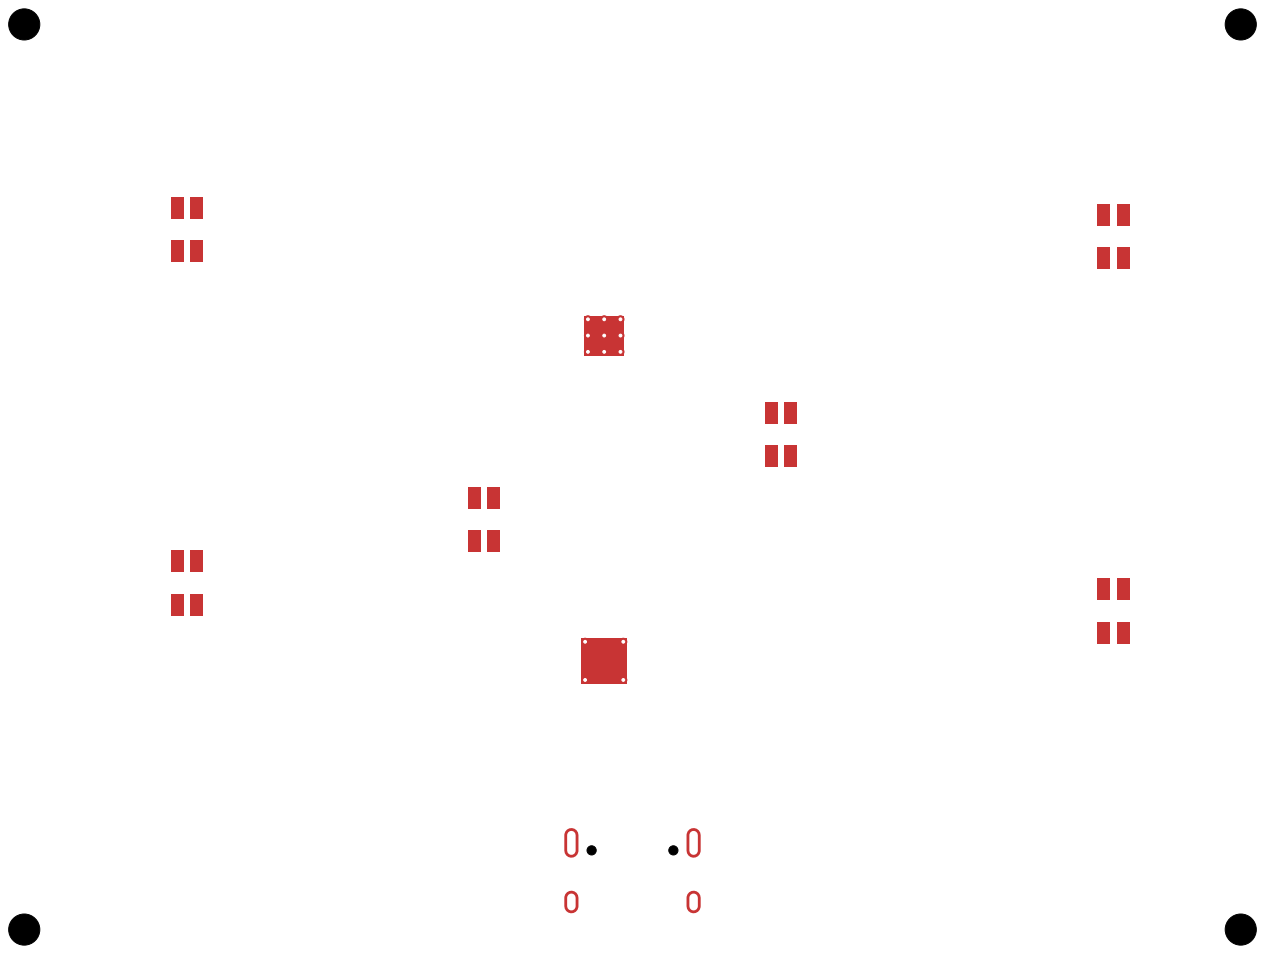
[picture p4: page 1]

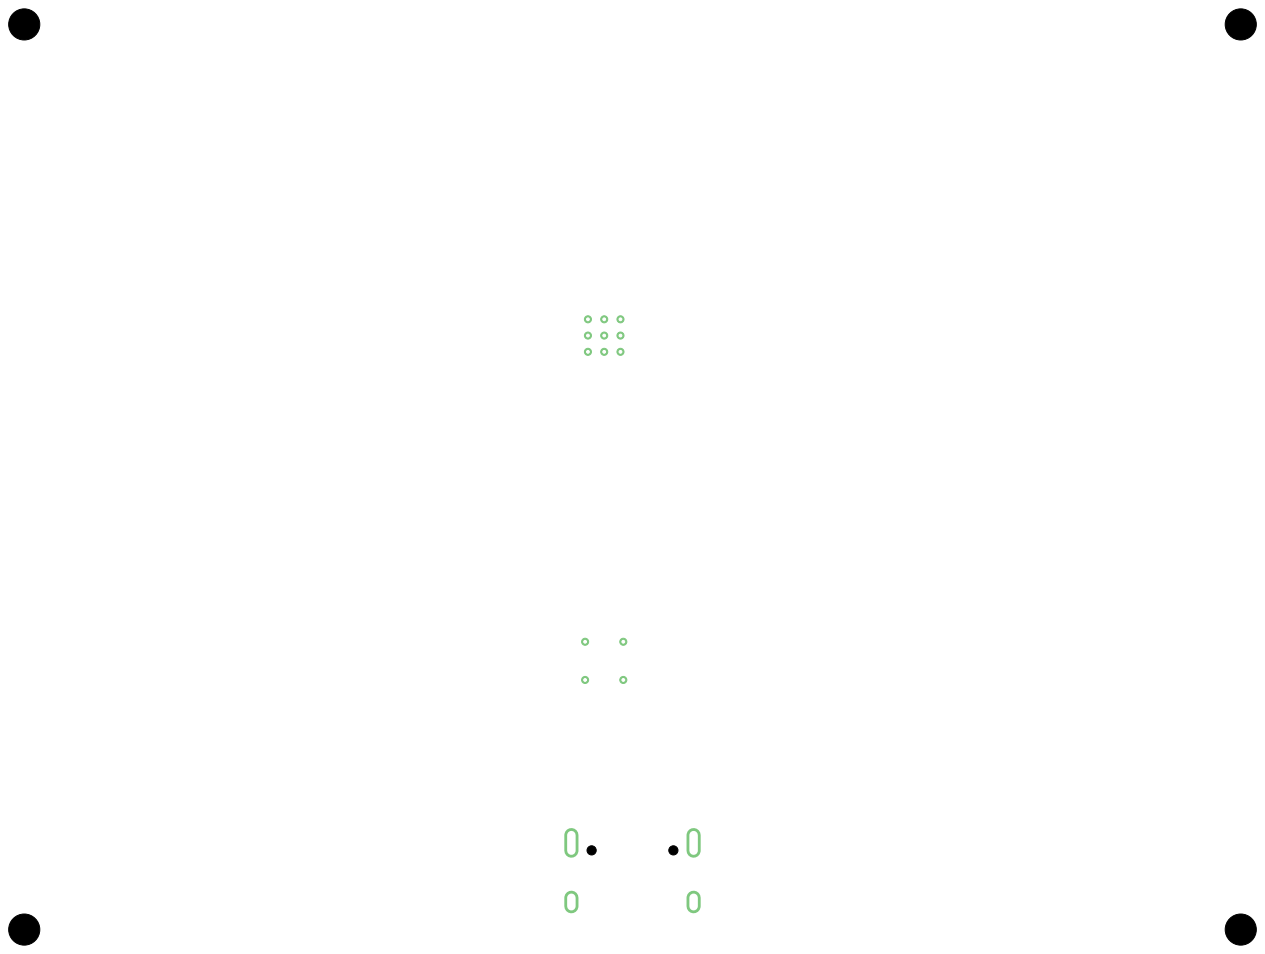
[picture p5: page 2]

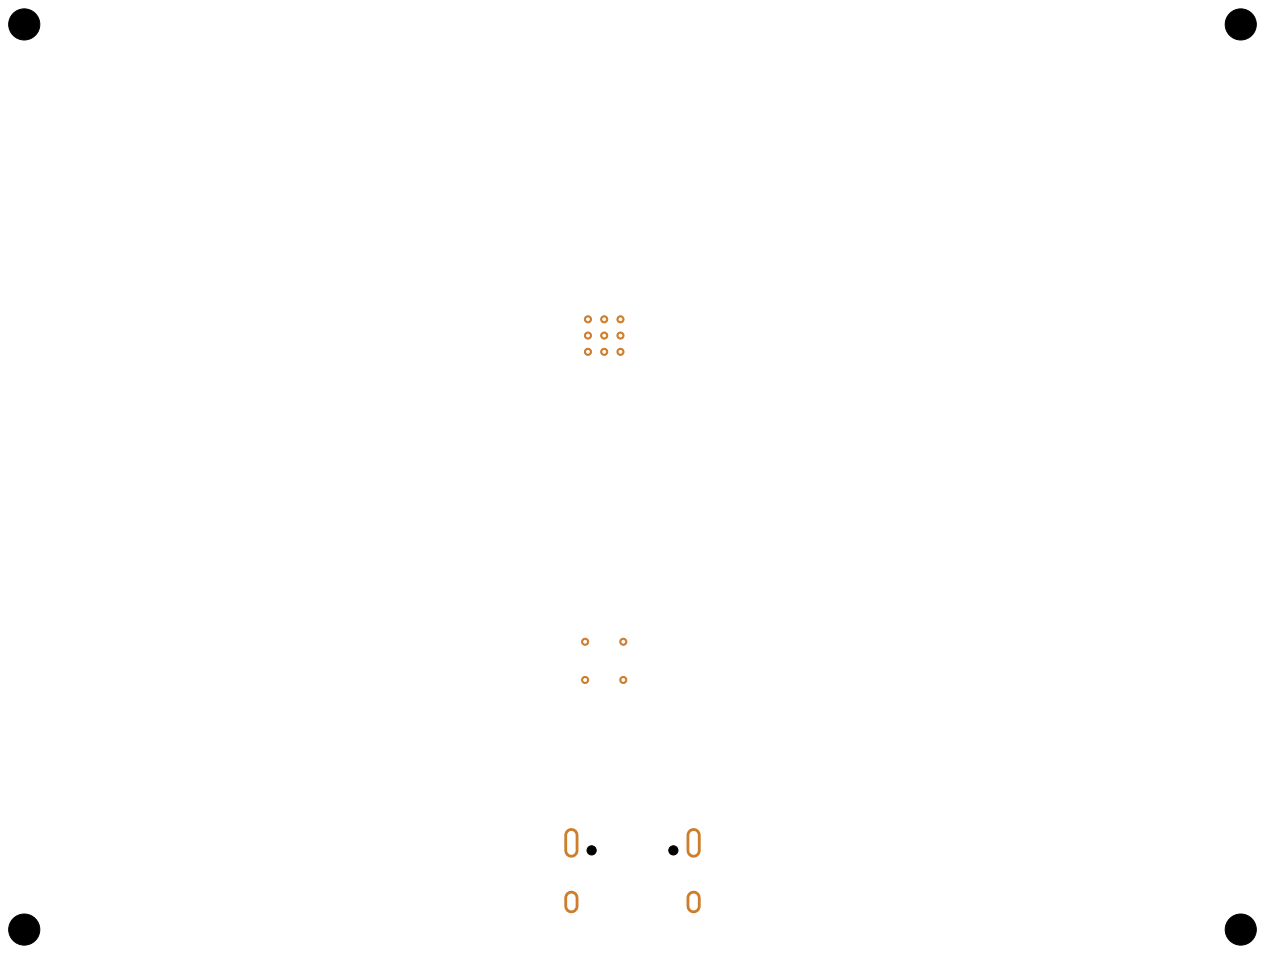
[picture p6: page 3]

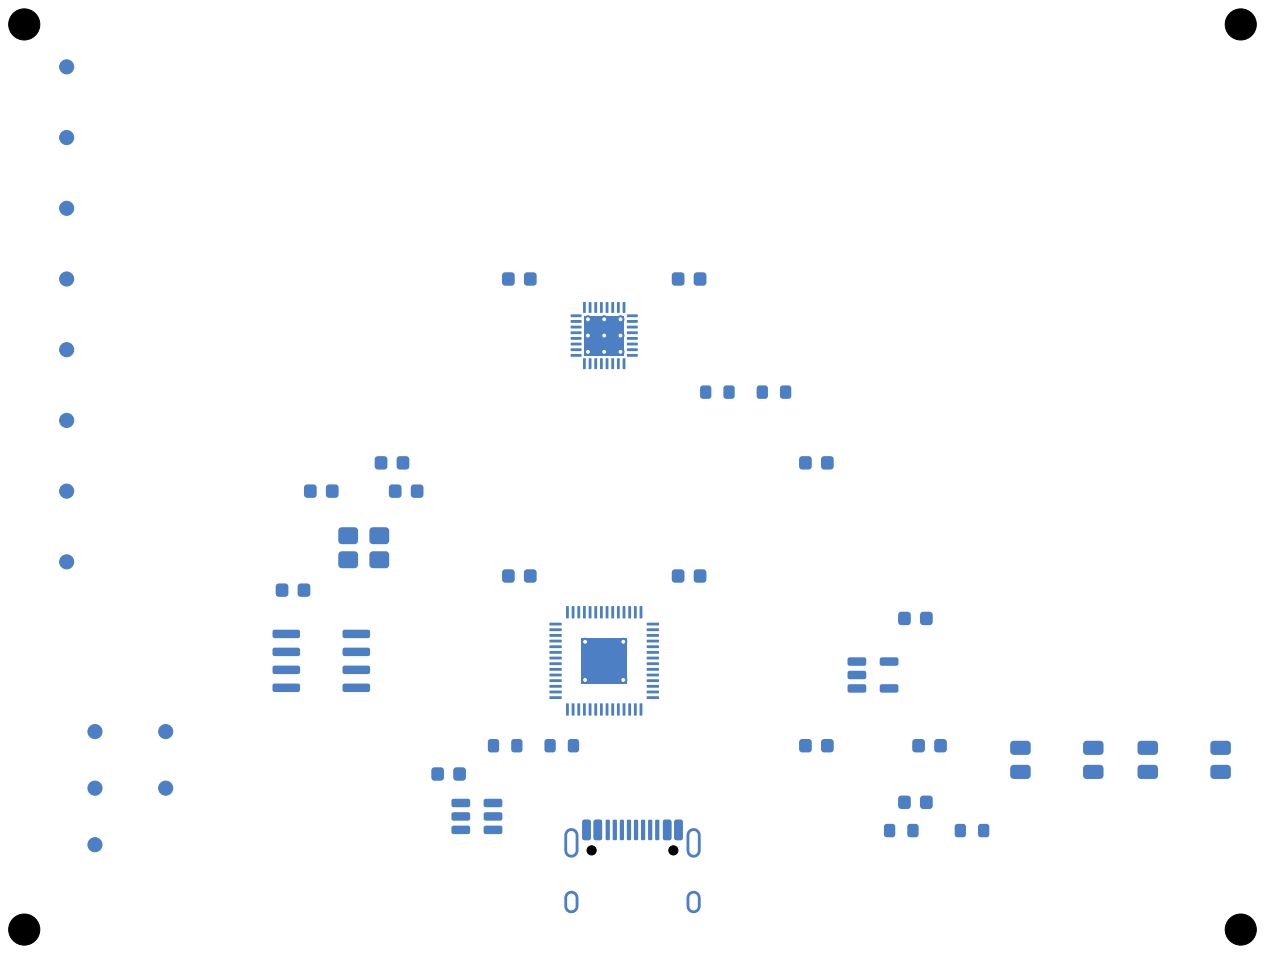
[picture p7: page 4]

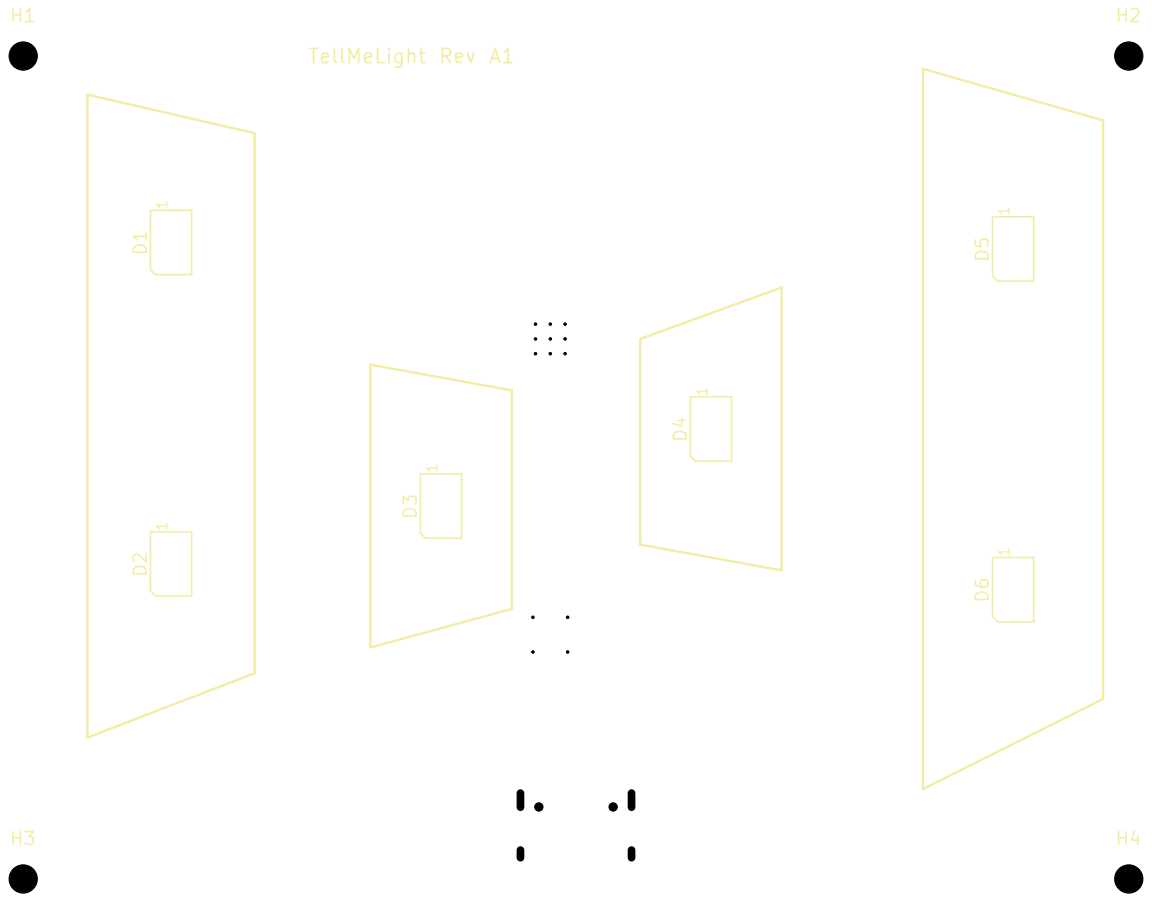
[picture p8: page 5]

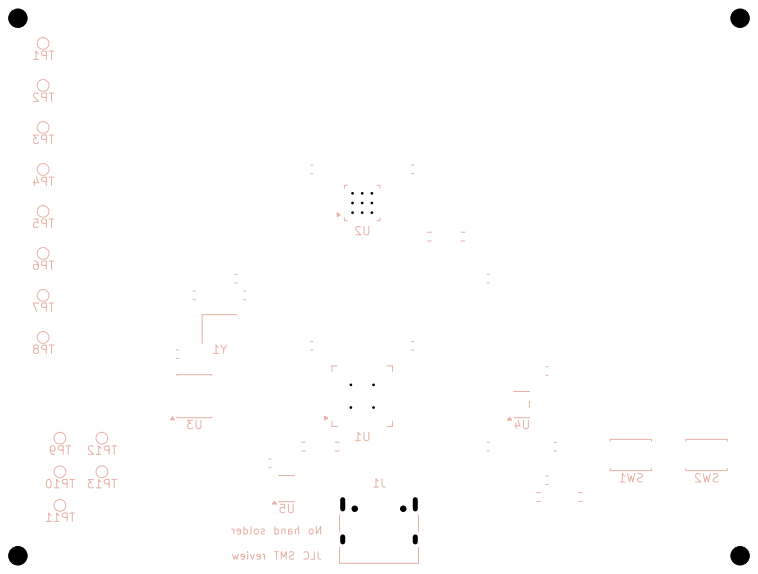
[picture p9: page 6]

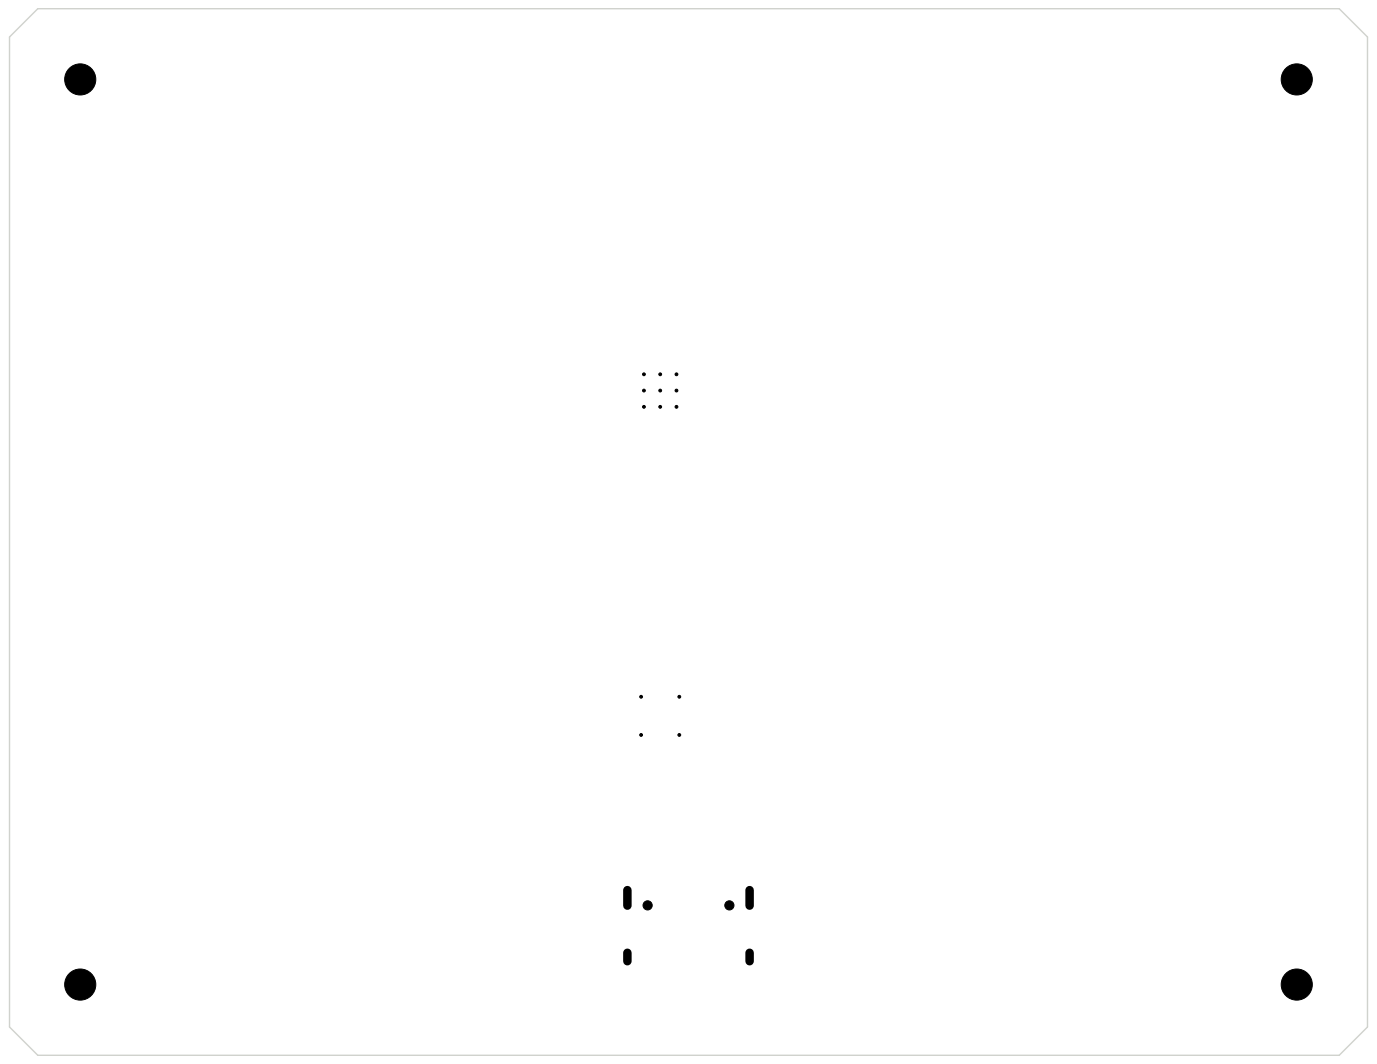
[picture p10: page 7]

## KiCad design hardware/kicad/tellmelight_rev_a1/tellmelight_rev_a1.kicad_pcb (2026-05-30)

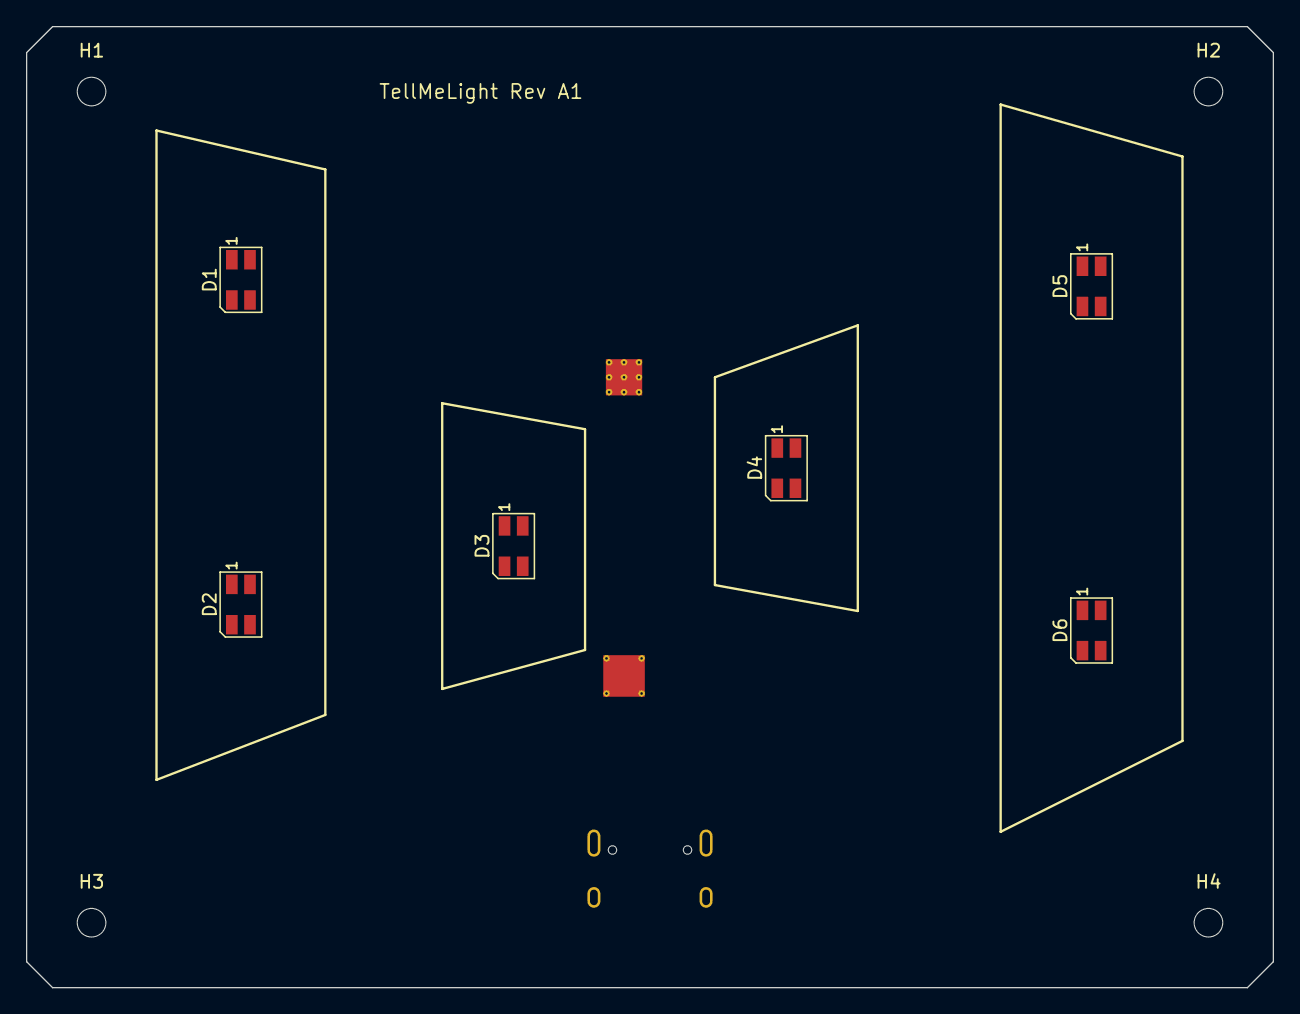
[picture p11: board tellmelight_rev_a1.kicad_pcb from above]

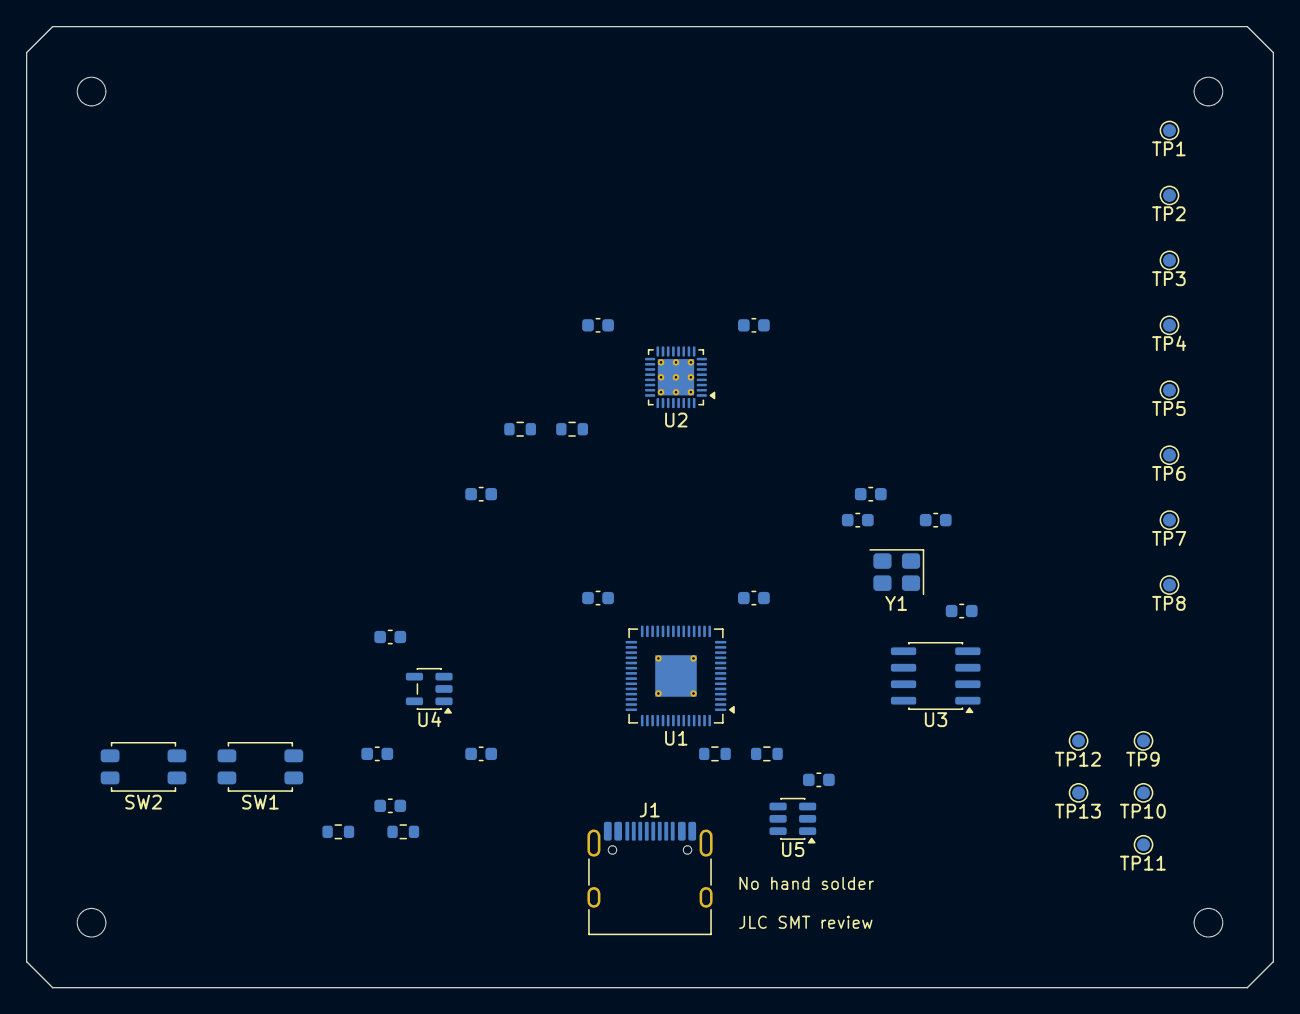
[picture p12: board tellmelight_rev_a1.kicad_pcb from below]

Board: 4 copper layers, 96.0 x 74.0 mm, 52 parts (42 on the bottom side), 4 nets, no tracks yet.

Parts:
C1, C2, C3, C4, C5, C6, C7, C8, C9, C10: 100nF; C_0603_1608Metric
C11, C12: 10uF; C_0603_1608Metric
C13, C14: CL; C_0603_1608Metric
D1, D2, D3, D4, D5, D6: S4-3528RGBTA-A; LED_RGB_Wuerth-PLCC4_3.2x2.8mm_150141M173100
H1, H2, H3, H4: M2; MountingHole_2.2mm_M2
J1: USB_C; USB_C_Receptacle_HRO_TYPE-C-31-M-12
R1, R2: 27R; R_0603_1608Metric
R3, R4: 5.1k; R_0603_1608Metric
R5, R6: 4.7k; R_0603_1608Metric
SW1: BOOT; SW_SPST_EVQP2_ShortPushTravel_H2.1mm
SW2: RESET; SW_SPST_EVQP2_ShortPushTravel_H2.1mm
TP1: VBUS; TestPoint_Pad_D1.0mm
TP2: 3V3; TestPoint_Pad_D1.0mm
TP3: GND; TestPoint_Pad_D1.0mm
TP4: SDA; TestPoint_Pad_D1.0mm
TP5: SCL; TestPoint_Pad_D1.0mm
TP6: D+; TestPoint_Pad_D1.0mm
TP7: D-; TestPoint_Pad_D1.0mm
TP8: RUN; TestPoint_Pad_D1.0mm
TP9: TP_SWDIO; TestPoint_Pad_D1.0mm
TP10: TP_SWCLK; TestPoint_Pad_D1.0mm
TP11: TP_RUN; TestPoint_Pad_D1.0mm
TP12: TP_3V3; TestPoint_Pad_D1.0mm
TP13: TP_GND; TestPoint_Pad_D1.0mm
U1: RP2040; QFN-56-1EP_7x7mm_P0.4mm_EP3.2x3.2mm_ThermalVias
U2: LP5024; VQFN-32-1EP_4x4mm_P0.4mm_EP2.8x2.8mm_ThermalVias
U3: W25Q32JVSS; SOIC-8_3.9x4.9mm_P1.27mm
U4: AP2112K-3.3; SOT-23-5
U5: TPD2EUSB30; SOT-23-6
Y1: 12MHz; Crystal_SMD_TXC_7M-4Pin_3.2x2.5mm

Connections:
GND_USB_A: J1.A1, J1.B12
GND_USB_B: J1.A12, J1.B1
VBUS_USB_A: J1.A4, J1.B9
VBUS_USB_B: J1.A9, J1.B4

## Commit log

2026-05-28 feat: encode HID display frames
2026-05-29 feat: select simulator slots
2026-05-30 docs: plan rev a kicad hardware
2026-05-30 feat: add rev a kicad hardware baseline
    [bom_from_kicad.csv, rev_a_bom.csv, rev_a_power_budget.csv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]
2026-05-30 feat: add rev a1 jlc hardware baseline
    [bom_from_kicad.csv, rev_a1_bom.csv, rev_a1_jlc_sourcing.csv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]
